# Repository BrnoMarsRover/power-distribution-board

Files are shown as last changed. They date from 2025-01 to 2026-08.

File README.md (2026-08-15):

# Power distribution board

Everything for the BrnoMarsRover power distribution board: the schematic and PCB, the
firmware that runs on it, and the ROS 2 driver that consumes it.

```
kicad/      schematic and PCB
pdf/        exported schematics
firmware/   Raspberry Pi Pico 2 sketch (Arduino, arduino-pico core)
ros2/       ROS 2 driver package (ament_python, Humble)
```

The firmware and the driver live together **because they share a versioned wire
protocol**. Every field name and status bit below is written twice - once in
`firmware/PowerBoard/Functions.cpp` and once in `ros2/powerboard/powerboard/powerboard_node.py`.
Splitting them across repositories would let the two halves be changed, reviewed and
deployed independently, and the failure mode is not a build error - it is silently
misparsed telemetry. Change the protocol in one commit, and bump `jsonSchemaVersion`
(firmware `Config.cpp`) together with `SUPPORTED_SCHEMA` (node) when you do.

## Hardware

Five INA238 current/voltage monitors on I2C, one per branch, each with a high-side
switch:

| Designator | I2C  | Shunt  | Rail | Limit |
|---|---|---|---|---|
| U2 | 0x40 | 3 mOhm | battery feed, and the master gate for the rest | 15 A |
| U3 | 0x41 | 5 mOhm | 24 V | 2.5 A |
| U4 | 0x42 | 5 mOhm | 15 V | 4 A |
| U5 | 0x43 | 5 mOhm | 12 V | 5 A |
| U6 | 0x44 | 5 mOhm | 5 V | 12 A |

Limits come from the 60 W rating of each DC-DC converter.

**Over-current protection ships disabled** (`ocpEnabled = false`). Some high-side
drivers were tripped by inrush and are bridged, so the board cannot actually switch
those branches off. Limits are still evaluated and reported, so an overload is visible
in telemetry even though nothing acts on it. `OCP ON` enables tripping if the hardware
is ever repaired.

Two things the board cannot measure, by construction:

- **Charging current.** The charger is wired on the battery side of U2's shunt, so
  charge current never crosses it. The driver infers charging from rising open-circuit
  voltage instead.
- **Currents above ~8 A on the INA CURRENT register**, which saturates there. The
  shunt-derived value is used for protection and for the `i` field because it has the
  range; `ir` is kept alongside it only for cross-checking.

## Serial protocol (schema v1)

USB CDC-ACM, one JSON object per line, telemetry at 2 Hz. Anything not starting with
`{` is human-readable diagnostics (`STATUS`, `RAW`) and is ignored by machine readers.

`"t"` gives the line type: `tel`, `evt`, `ack`, `err`, `info`.

### `tel` - periodic telemetry

```json
{"t":"tel","v":1,"seq":123,"up":61500,"ocp":0,"mst":1,"b":[ ... ]}
```

| Key | Meaning |
|---|---|
| `v` | schema version |
| `seq` | frame counter; gaps mean frames were lost |
| `up`  | milliseconds since board boot |
| `ocp` | 1 if over-current protection is enabled |
| `mst` | 1 if the U2 master branch is on |
| `b` | one object per branch |

Each branch object:

| Key | Unit | Meaning |
|---|---|---|
| `n` | | designator, `U2`..`U6` |
| `a` | | I2C address |
| `s` | | status bits, see below |
| `lim` | mA | configured current limit |
| `vb`  | V | bus voltage |
| `vs`  | mV | shunt voltage |
| `i` | mA | current derived from the shunt - **this is the real one** |
| `ir`  | mA | INA CURRENT register, saturates at ~8 A, cross-check only |
| `tc`  | degC | INA die temperature |
| `tr`  | | cumulative trip count |

Status bits in `s`:

| Bit  | Name |
|---|---|
| 0x01 | online |
| 0x02 | enabled |
| 0x04 | tripped |
| 0x08 | manual off  |
| 0x10 | powered |
| 0x20 | over limit  |

### `evt` - pushed immediately, not on the telemetry tick

```json
{"t":"evt","up":61500,"ev":"over_limit","n":"U5","i":5200.0,"lim":5000,"ocp":0}
```

`ev` is one of `over_limit`, `over_limit_clear`, `ocp_trip`, `ocp_recover`. These are
pushed as they happen because with OCP disabled an over-limit event is the only
actionable signal the board can give.

### `ack` / `err` / `info`

```json
{"t":"ack","cmd":"JSON","msg":"json output"}
{"t":"err","cmd":"OFF U9","msg":"unknown branch"}
{"t":"info","fw":"...","v":1,"rails":5,"ocp":0}
```

### Commands (host to board, one per line)

| Command | Effect |
|---|---|
| `ON <U>` | switch a branch on |
| `OFF <U>` | switch a branch off |
| `OCP [ON|OFF]` | query or set over-current protection |
| `RAW` | dump every INA238 register, human readable |
| `STATUS` | human readable summary |
| `JSON` | machine-readable output (the default) |
| `HUMAN` | switch to the plain-text table |
| `ONCE` | emit a single telemetry frame |

## Firmware

Arduino sketch in `firmware/PowerBoard`, target Raspberry Pi Pico 2 (`rpipico2`),
arduino-pico core 5.5.1. Open `PowerBoard.ino` and flash it.

## ROS 2 driver

`ros2/powerboard`, ament_python, tested on Humble. Depends only on `rclpy`,
`std_msgs`, `sensor_msgs`, `diagnostic_msgs` and `python3-serial` - no custom
interfaces.

```bash
ros2 launch powerboard powerboard.launch.py
```

| Topic | Type |
|---|---|
| `~/battery` | `sensor_msgs/BatteryState` |
| `~/rails/voltages` | `std_msgs/Float32MultiArray` |
| `~/rails/currents` | `std_msgs/Float32MultiArray` |
| `~/rails/powers` | `std_msgs/Float32MultiArray` |
| `~/events` | `std_msgs/String` |
| `~/command` | `std_msgs/String` (subscription, forwards any board command) |
| `/diagnostics` | `diagnostic_msgs/DiagnosticArray` |

The rail arrays carry names in `layout.dim[i].label`, index-aligned with `data[i]`.

State of charge is estimated from a LiPo open-circuit-voltage curve, load-compensated
and smoothed, and published in `BatteryState.percentage`. It is a rough guide, not a
fuel gauge: between about 3.8 and 3.9 V/cell the curve is nearly flat, and below
3.7 V/cell it falls away sharply. Defaults assume Freya's **10S, 14.5 Ah** pack; see
`cell_count`, `design_capacity_ah` and `pack_resistance_ohm`.

**Only one process may hold the serial port.** Two readers steal bytes from each other,
which looks exactly like a flaky board - sequence gaps and a halved frame rate.

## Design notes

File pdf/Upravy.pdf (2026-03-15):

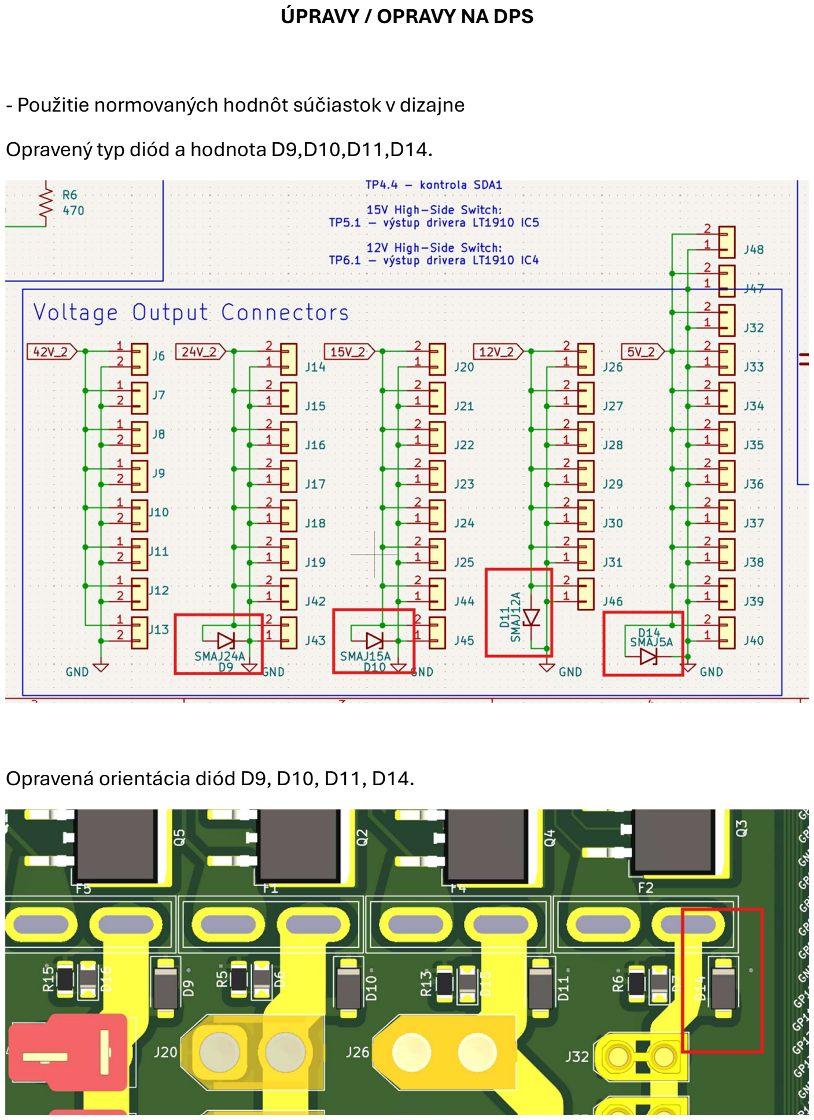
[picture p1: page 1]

ÚPRAVY / OPRAVY NA DPS

- Použitie normovaných hodnôt súčiastok v dizajne Opravený typ diód a hodnota D9,D10,D11,D14.

Opravená orientácia diód D9, D10, D11, D14.

- Zmeny hodnôt komponentov Opravene hodnoty komponentov: 5,5nF -> 5,6nF
5kOhm -> 4,7kOhm
BC818 -> BC817
- Dióda D2 a konektor J5
Boli vymazané D2 a J5, ktoré predstavovali pozostatok návrhu, ktorý uvažoval o sekundárnom zdroji energie zo solárneho panelu.
- zväčšené plôšky na Qx, L

-upravené cesty a prepoje medzi F.Cu a B.Cu

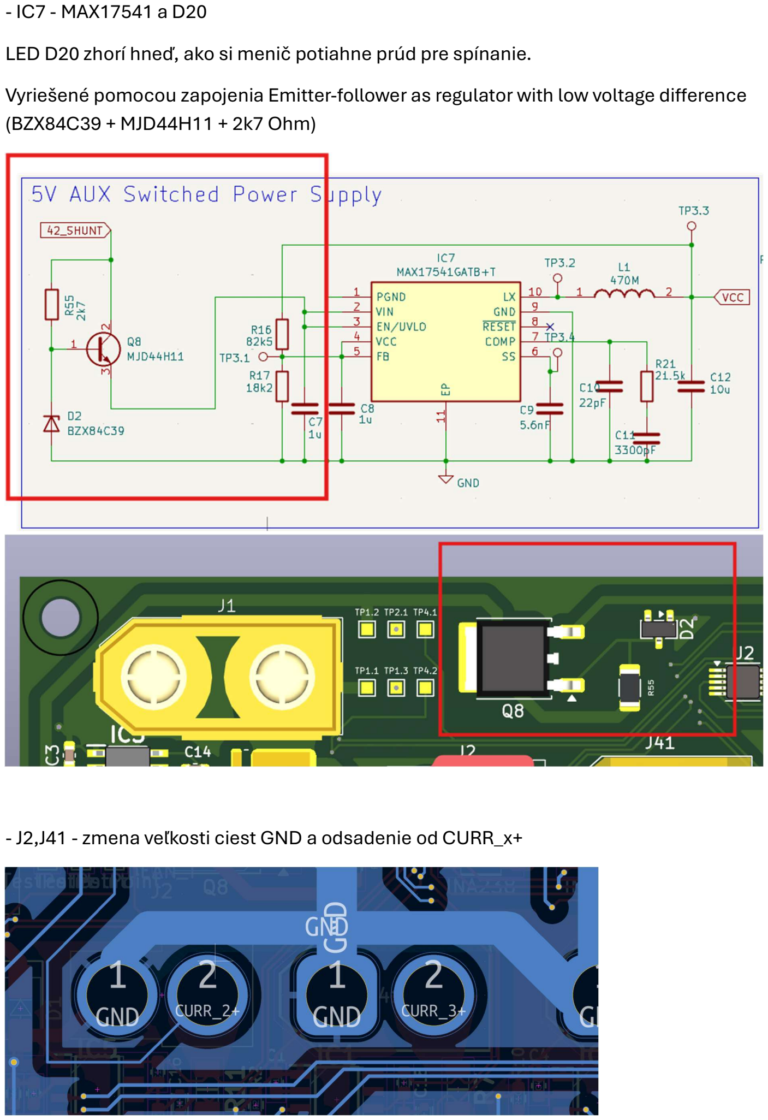
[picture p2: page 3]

- IC7 - MAX17541 a D20
LED D20 zhorí hneď, ako si menič potiahne prúd pre spínanie.
Vyriešené pomocou zapojenia Emitter-follower as regulator with low voltage dierence (BZX84C39 + MJD44H11 + 2k7 Ohm)
- J2,J41 - zmena veľkosti ciest GND a odsadenie od CURR_x+

- Chýbajúce prepojenia na DPS
Boli doplnené chýbajúce prepojenia pre: IC1 -> C1

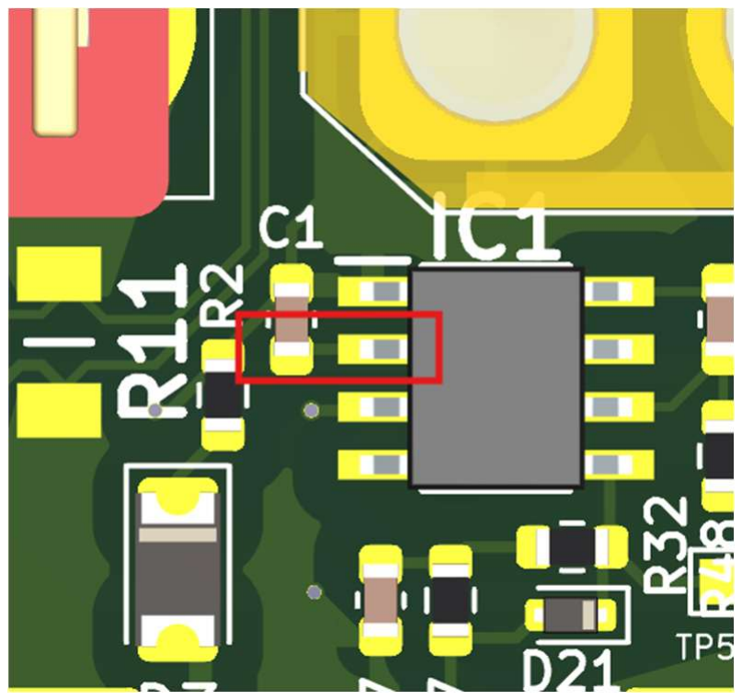
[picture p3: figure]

IC4 -> C4

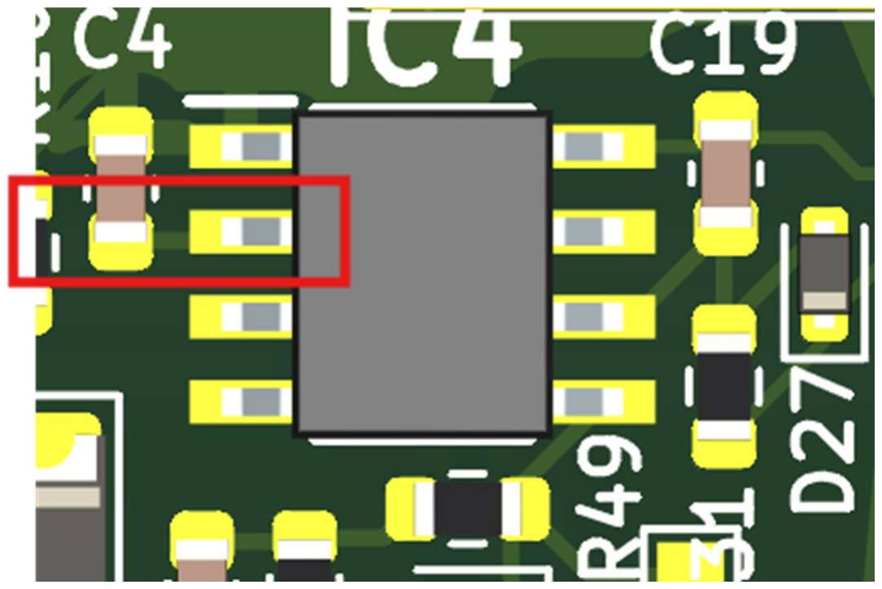
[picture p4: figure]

Q5 -> D13

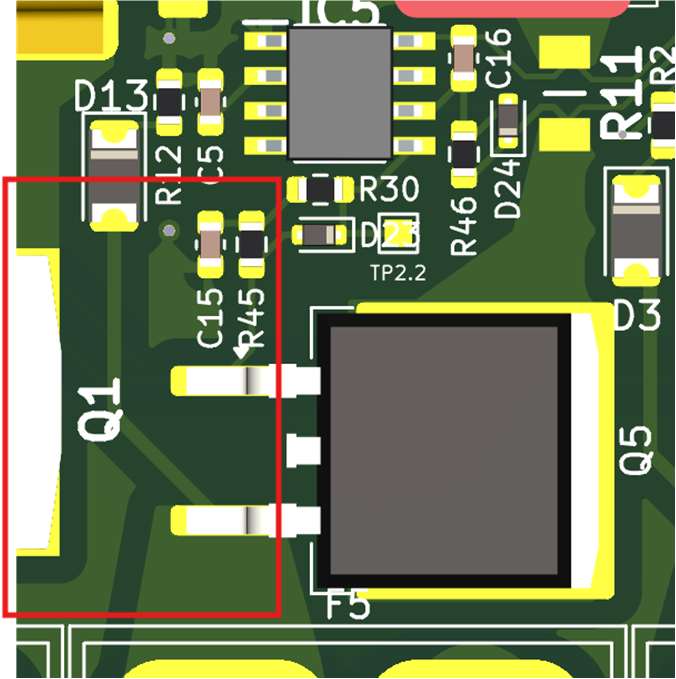
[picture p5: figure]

- test points
Boli doplnené TestPoints pre:

Battery Voltage High-Side Switch:

TP1.1 - kontrola vstupného napätia batérie

TP1.2 - napätie pred MOSFETom, kontrola shuntu

TP1.3 - kontrola gate drive IC3-Q1

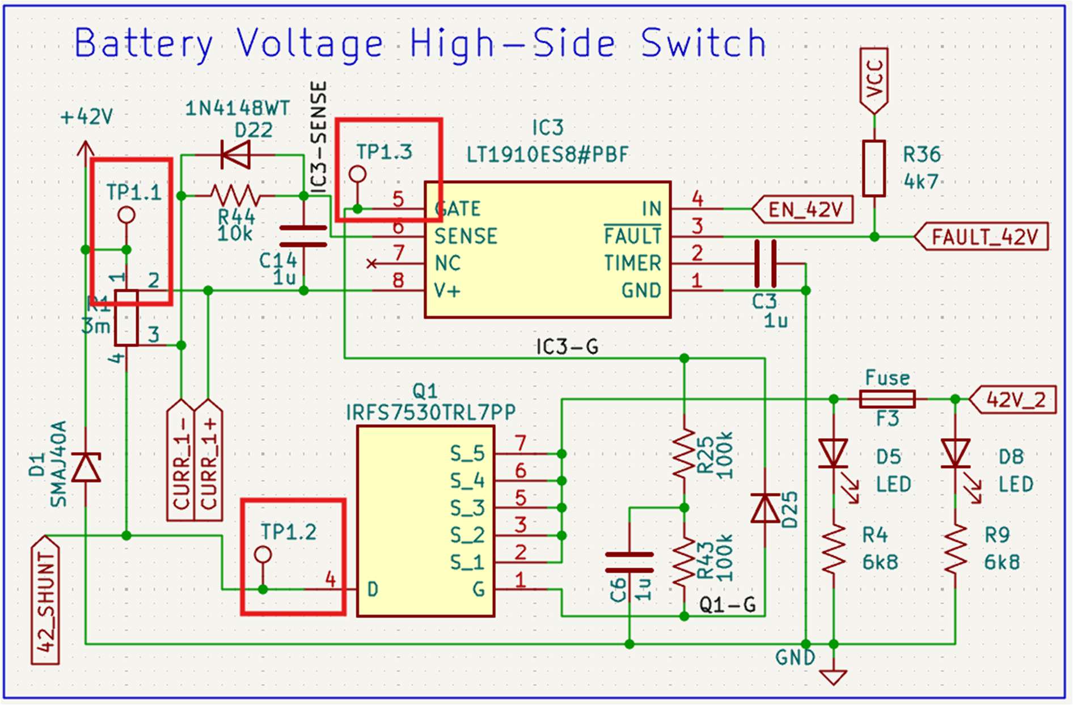
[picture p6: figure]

24V High-Side Switch:

TP2.1 - kontrola vstupného napätia 24V

TP2.2 - výstup drivera LT1910 IC5

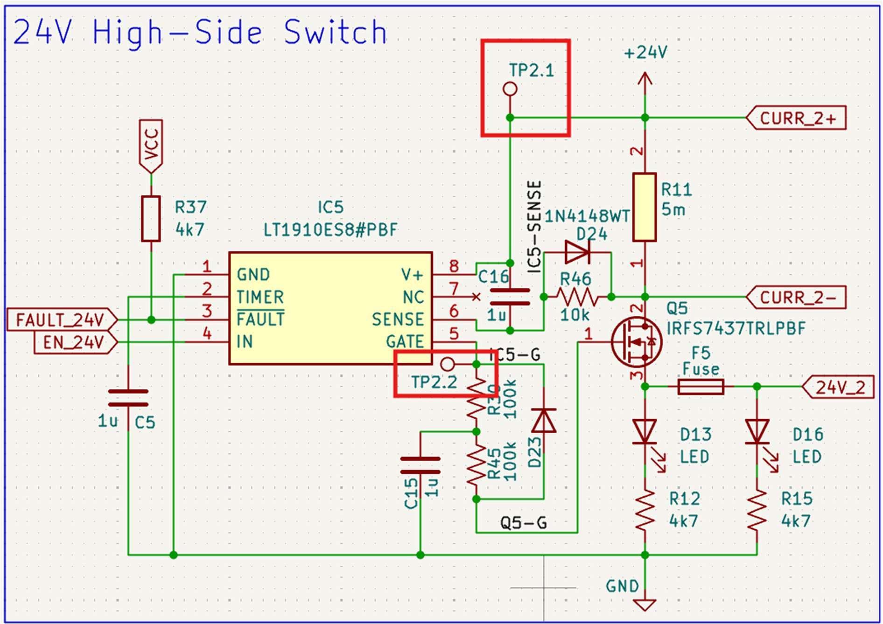
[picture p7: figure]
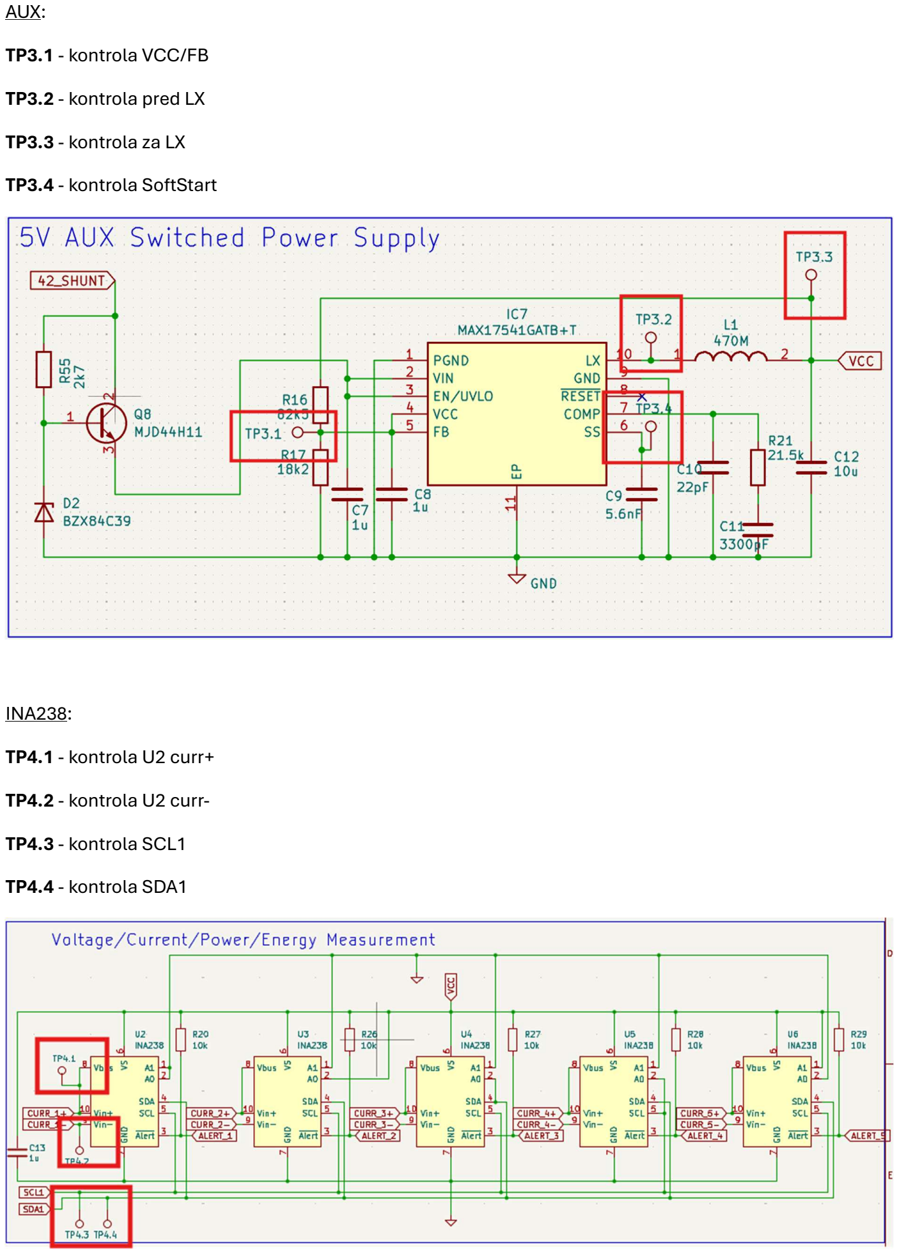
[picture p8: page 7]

AUX:

TP3.1 - kontrola VCC/FB

TP3.2 - kontrola pred LX

TP3.3 - kontrola za LX

TP3.4 - kontrola SoftStart

INA238:

TP4.1 - kontrola U2 curr+

TP4.2 - kontrola U2 curr-

TP4.3 - kontrola SCL1

TP4.4 - kontrola SDA1

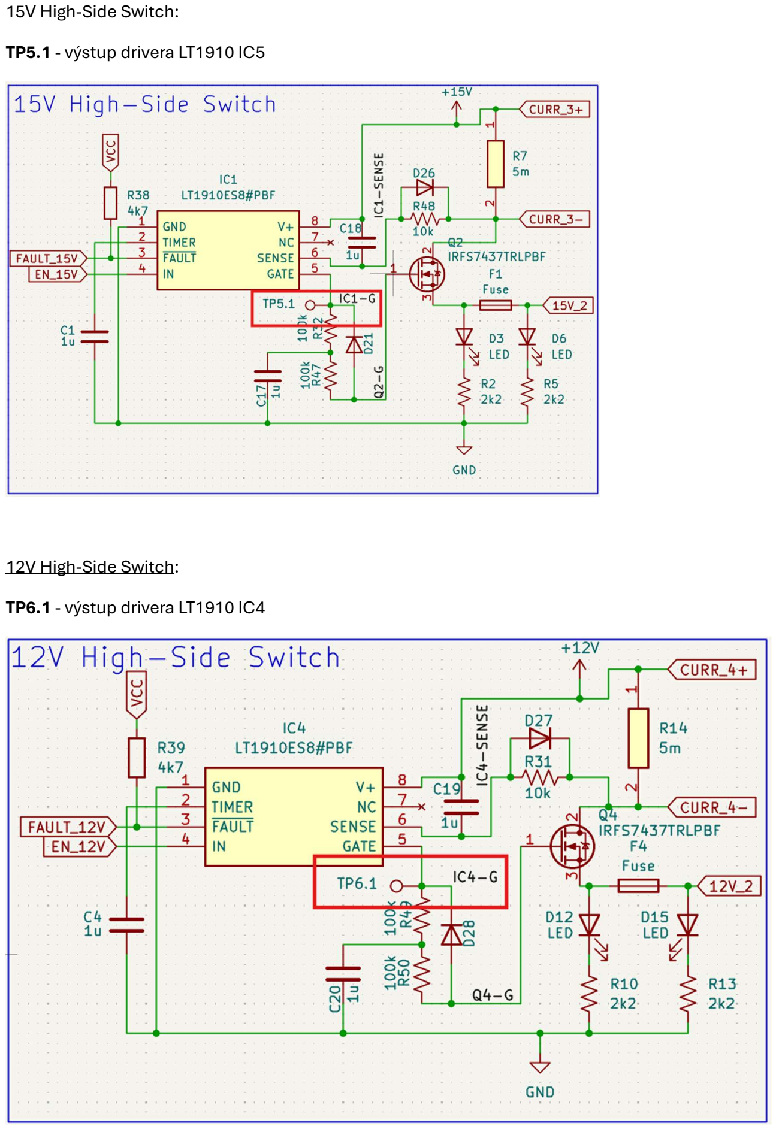
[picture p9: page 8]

15V High-Side Switch:

TP5.1 - výstup drivera LT1910 IC5

12V High-Side Switch:

TP6.1 - výstup drivera LT1910 IC4

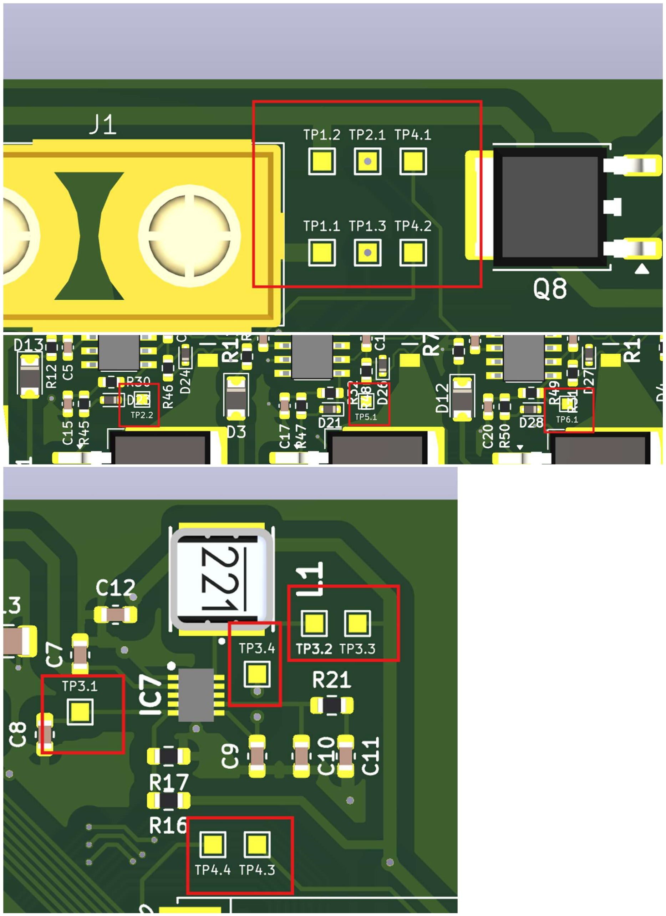
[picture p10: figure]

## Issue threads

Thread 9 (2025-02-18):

Zaintegrovat powerboard v2.3.0 spolu se zdroji a otestovat všechny napěťové úrovně

rem821, 2025-02-18:

rem821, 2025-02-21:
Při zapojení všech spínaných zdrojů se z důdovů vysoké kapacitní zátěže a tudíž vysokého startovního proudu zapne nadproudová ochrana u driveru mosfetu. Bude třeba tento vstupní proud v první chvíli omezit. Zároveň při vypínání kapacitní zátěže je nutné zamezit Ugsmax zenerkou.

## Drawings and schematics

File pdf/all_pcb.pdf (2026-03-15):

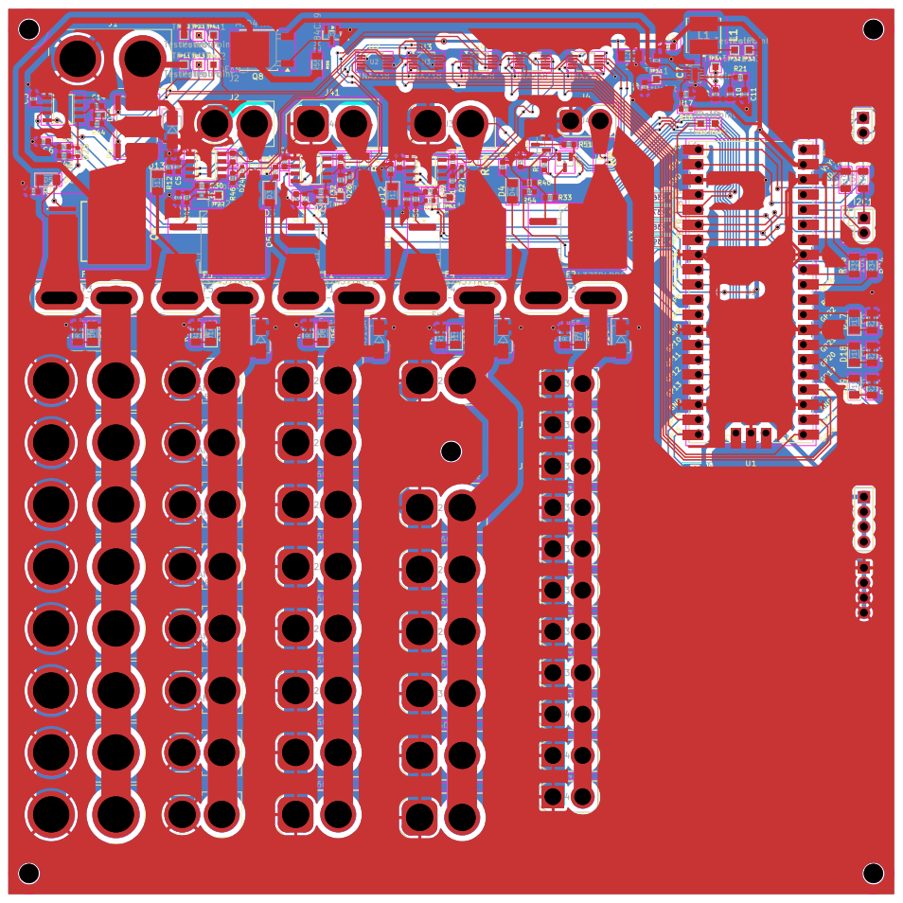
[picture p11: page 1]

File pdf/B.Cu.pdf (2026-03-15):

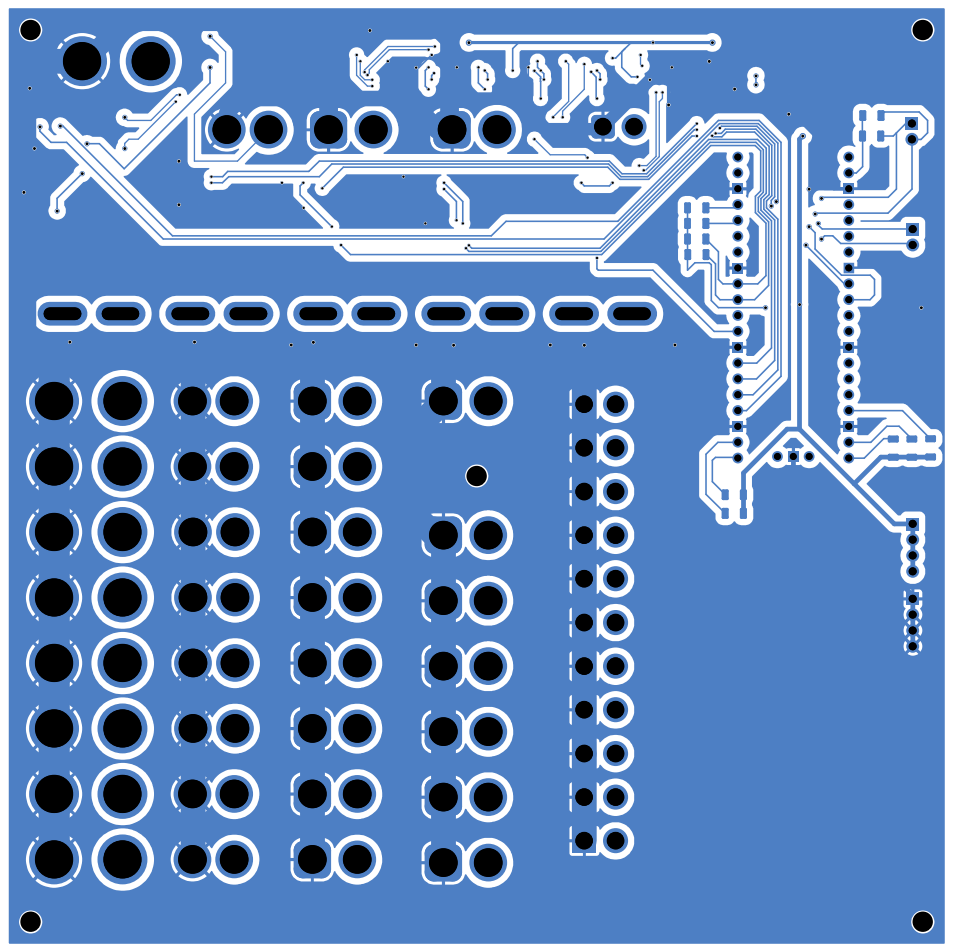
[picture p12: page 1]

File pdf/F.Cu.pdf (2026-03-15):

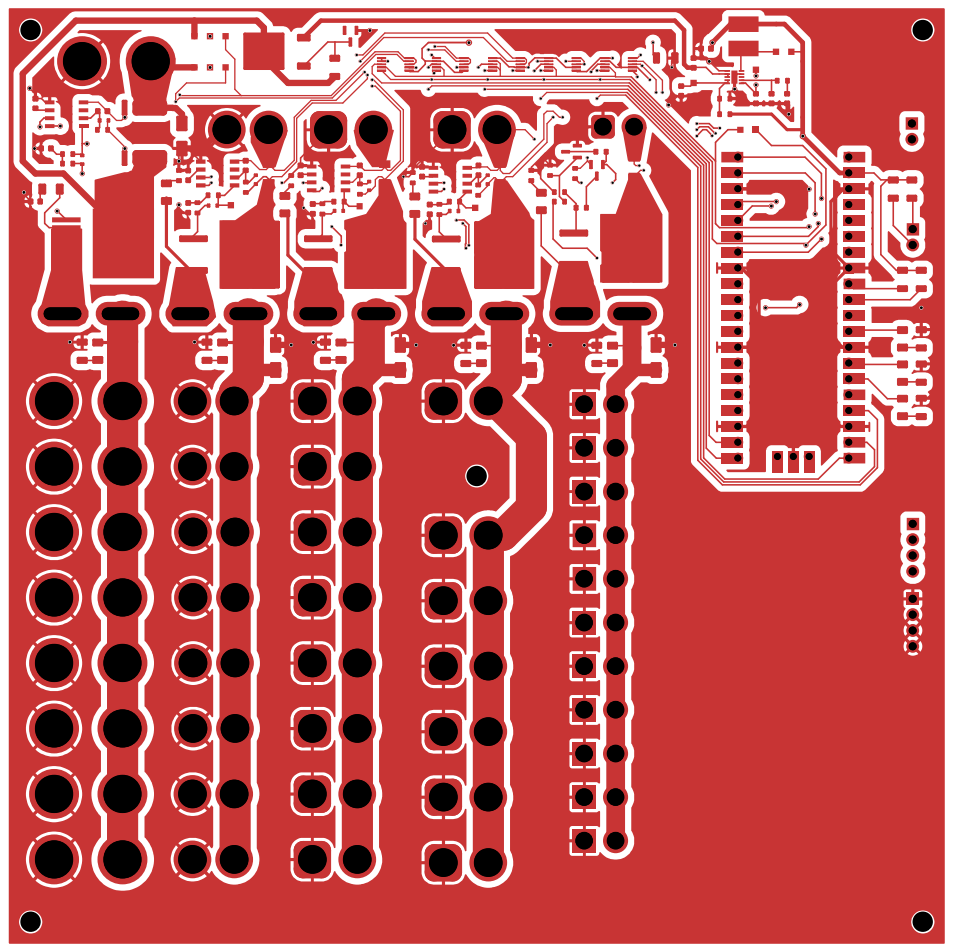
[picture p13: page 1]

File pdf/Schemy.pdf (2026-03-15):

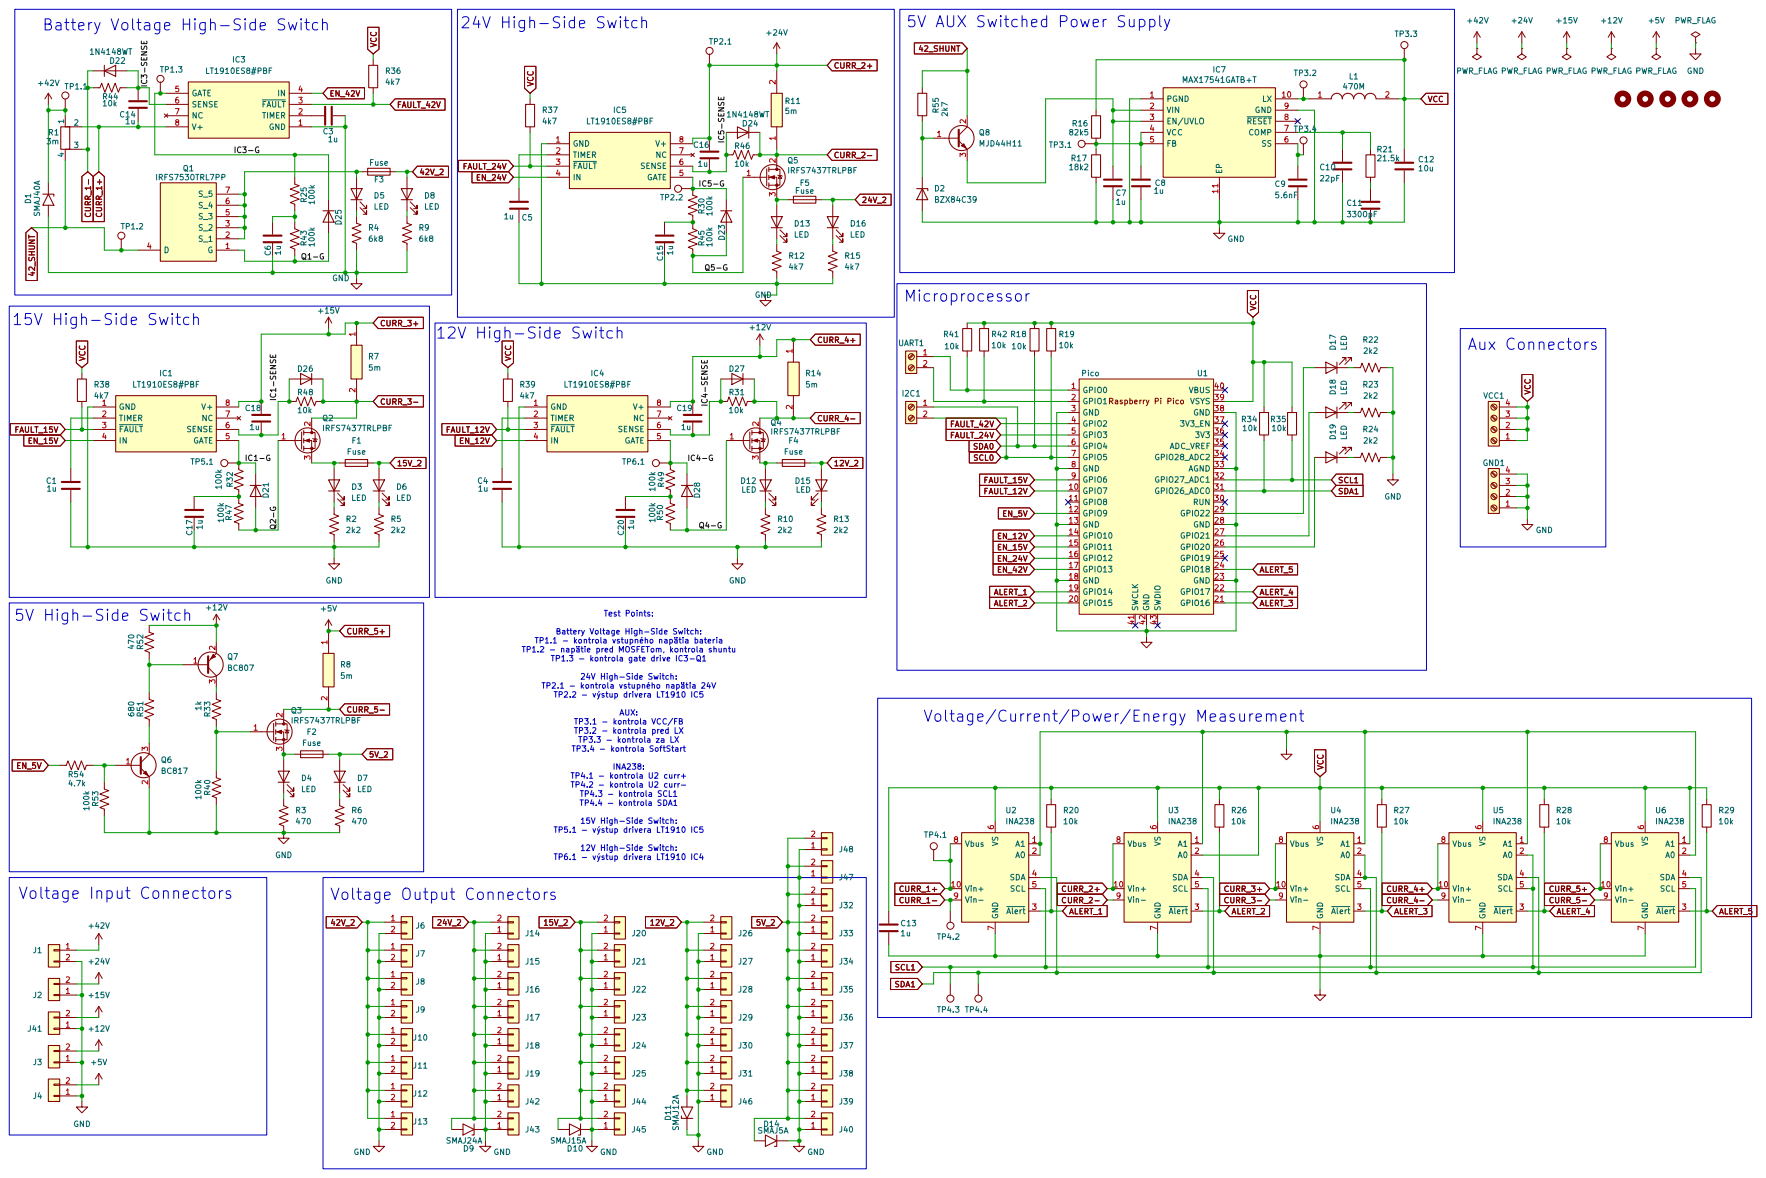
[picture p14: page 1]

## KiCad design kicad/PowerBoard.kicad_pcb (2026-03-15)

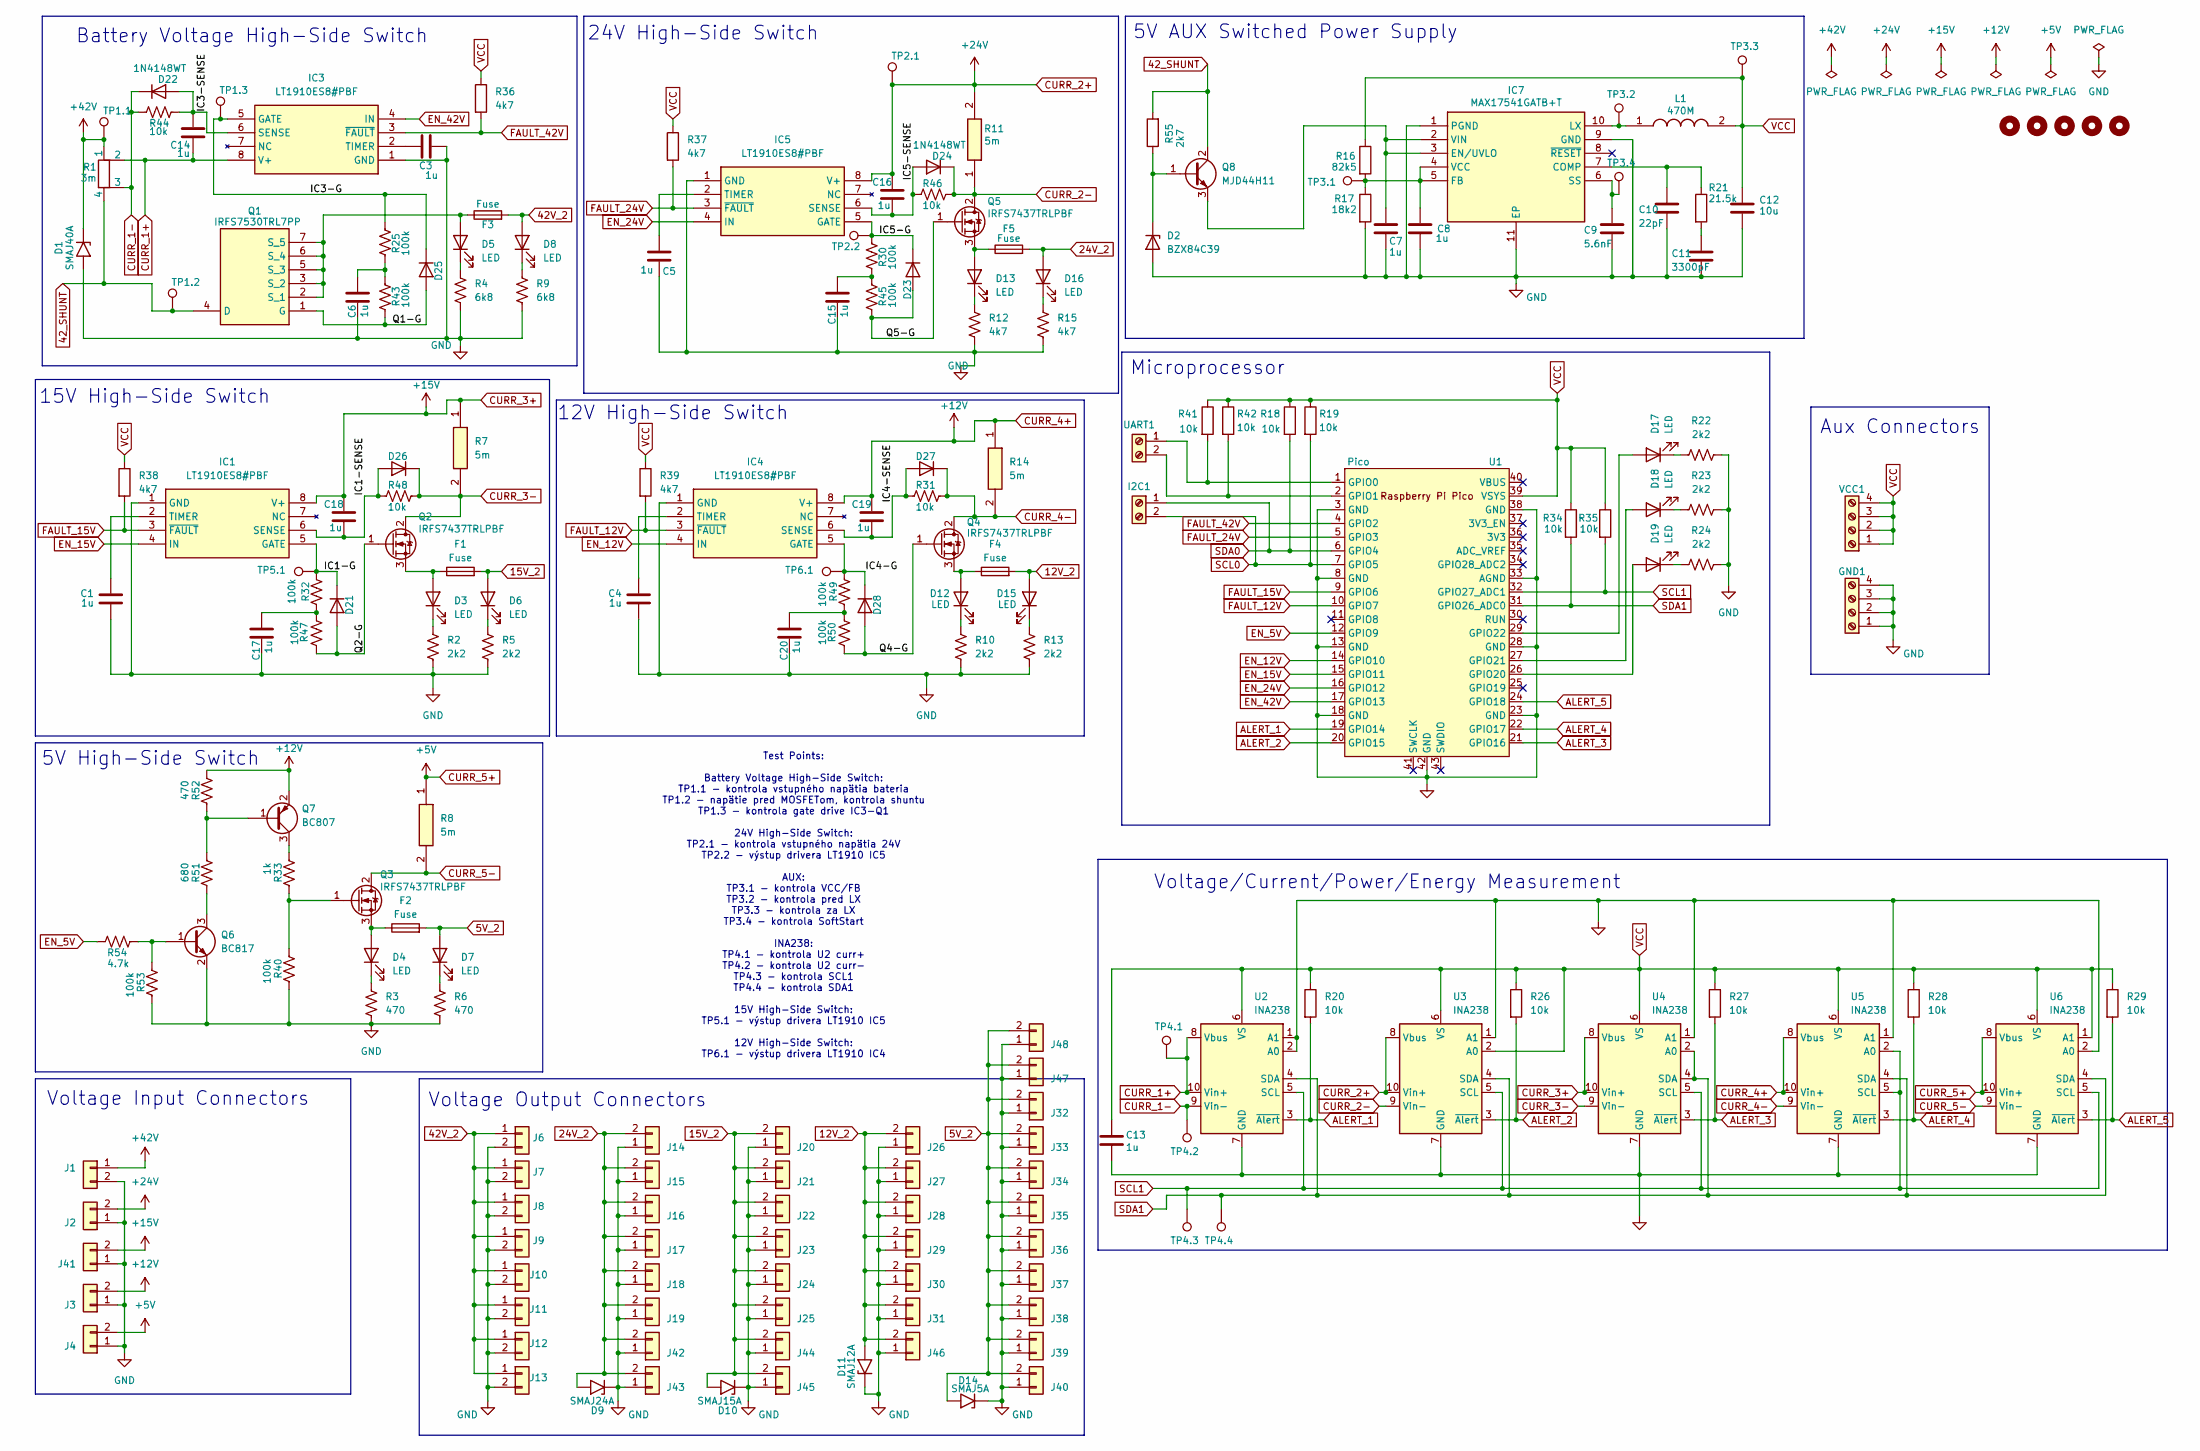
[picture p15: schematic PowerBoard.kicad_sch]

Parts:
C1, C3, C4, C5, C6, C7, C8, C14, C15, C16, C17, C18, C19, C20: 1u; C_0603_1608Metric
C9: 5.6nF; C_0603_1608Metric
C10: 22pF; C_0603_1608Metric
C11: 3300pF; C_0603_1608Metric
C12: 10u; C_0603_1608Metric
C13: 1u; C_1206_3216Metric
D1: SMAJ40A; D_SMA
D2: BZX84C39; SOT-23
D3, D4, D5, D6, D7, D8, D12, D13, D15, D16, D17, D18, D19: LED; D_1206_3216Metric
D9: SMAJ24A; D_SMA
D10: SMAJ15A; D_SMA
D11: SMAJ12A; D_SMA
D14: SMAJ5A; D_SMA
D21, D22, D23, D24, D25, D26, D27, D28: 1N4148WT; D_SOD-523
F1, F2, F3, F4, F5: Fuse; Fuse_Blade_ATO_directSolder
GND1: Screw_Terminal_01x04; TerminalBlock_Xinya_XY308-2.54-4P_1x04_P2.54mm_Horizontal
H1, H2, H3, H4, H5: MountingHole; MountingHole_3.2mm_M3
I2C1: Screw_Terminal_01x02; TerminalBlock_Xinya_XY308-2.54-2P_1x02_P2.54mm_Horizontal
IC1, IC3, IC4, IC5: LT1910ES8#PBF; SOIC127P599X175-8N; Mouser Part Number 584-LT1910ES8#PBF
IC7: MAX17541GATB+T; SON50P200X300X80-11N; Mouser Part Number 700-MAX17541GATB+T
J1, J6, J7, J8, J9, J10, J11, J12, J13: XT90
J2, J14, J15, J16, J17, J18, J19, J42, J43: DEAN_T; DEANS-T
J3, J20, J21, J22, J23, J24, J25, J26, J27, J28, J29, J30, J31, J41, J44, J45, J46: XT60; AMASS_XT60-F_1x02_P7.20mm_Vertical
J4, J32, J33, J34, J35, J36, J37, J38, J39, J40, J47, J48: XT30; AMASS_XT30U-F_1x02_P5.0mm_Vertical
L1: 470M; SRR5828A2R6Y; Mouser Part Number 6521-SRR5828A-470M
Q1: IRFS7530TRL7PP; Mouser Part Number 942-IRFS7530TRL7PP
Q2, Q3, Q4, Q5: IRFS7437TRLPBF; TO-263-2
Q6: BC817; SOT-23
Q7: BC807; SOT-23
Q8: MJD44H11; TO-252-2
R1: 3m; R_Shunt_Isabellenhuette_BVR4026
R2, R10: 2k2; R_0603_1608Metric
R3, R52: 470; R_0603_1608Metric
R4: 6k8; C_0603_1608Metric
R5, R13, R22, R23, R24: 2k2; R_1206_3216Metric
R6: 470; R_1206_3216Metric
R7, R8, R11, R14: 5m; RESC3216X89N; Mouser Part Number 71-WSL12061L000FEA
R9: 6k8; R_1206_3216Metric
R12: 4k7; R_0603_1608Metric
R15, R36, R37, R38, R39: 4k7; R_1206_3216Metric
R16: 82k5; R_0603_1608Metric
R17: 18k2; R_0603_1608Metric
R18, R19, R20, R26, R27, R28, R29, R34, R35, R41, R42: 10k; R_1206_3216Metric
R21: 21.5k; R_0603_1608Metric
R25, R30, R32, R40, R43, R45, R47, R49, R50, R53: 100k; R_0603_1608Metric
R31, R44, R46, R48: 10k; R_0603_1608Metric
R33: 1k; R_0603_1608Metric
R51: 680; R_0603_1608Metric
R54: 4.7k; R_0603_1608Metric
R55: 2k7; R_1206_3216Metric
TP1.1, TP1.2, TP1.3, TP2.1, TP2.2, TP3.1, TP3.2, TP3.3, TP3.4, TP4.1, TP4.2, TP4.3, TP4.4, TP5.1, TP6.1: TestPoint; TestPoint_Pad_1.0x1.0mm
U1: Pico; RPi_Pico_SMD_TH
U2, U3, U4, U5, U6: INA238; VSSOP-10_3x3mm_P0.5mm
UART1: Screw_Terminal_01x02; TerminalBlock_Xinya_XY308-2.54-2P_1x02_P2.54mm_Horizontal
VCC1: Screw_Terminal_01x04; TerminalBlock_Xinya_XY308-2.54-4P_1x04_P2.54mm_Horizontal

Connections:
5V_2: D7.2 (A), D14.2 (A2), F2.2, J32.2, J33.2, J34.2, J35.2, J36.2, J37.2, J38.2, J39.2, J40.2, J47.2, J48.2
12V_2: D11.2 (A2), D15.2 (A), F4.2, J26.2, J27.2, J28.2, J29.2, J30.2, J31.2, J46.2
15V_2: D6.2 (A), D10.2 (A2), F1.2, J20.2, J21.2, J22.2, J23.2, J24.2, J25.2, J44.2, J45.2
24V_2: D9.2 (A2), D16.2 (A), F5.2, J14.2, J15.2, J16.2, J17.2, J18.2, J19.2, J42.2, J43.2
42V_2: D8.2 (A), F3.2, J6.1, J7.1, J8.1, J9.1, J10.1, J11.1, J12.1, J13.1
42_SHUNT: Q1.4 (D), Q8.2 (C), R1.4, R55.2, TP1.2.1
+42V: D1.1 (A1), J1.1, R1.1, TP1.1.1
/IC1-G: D21.1 (K), IC1.5 (GATE), R32.2, TP5.1.1
/IC1-SENSE: C18.2, D26.2 (A), IC1.6 (SENSE), R48.1
/IC3-G: D25.1 (K), IC3.5 (GATE), R25.2, TP1.3.1
/IC3-SENSE: C14.1, D22.2 (A), IC3.6 (SENSE), R44.2
/IC4-G: D28.1 (K), IC4.5 (GATE), R49.2, TP6.1.1
/IC4-SENSE: C19.2, D27.2 (A), IC4.6 (SENSE), R31.1
/IC5-G: D23.1 (K), IC5.5 (GATE), R30.2, TP2.2.1
/IC5-SENSE: C16.2, D24.2 (A), IC5.6 (SENSE), R46.1
/Q1-G: D25.2 (A), Q1.1 (G), R43.2
/Q2-G: D21.2 (A), Q2.1 (G), R47.2
/Q4-G: D28.2 (A), Q4.1 (G), R50.2
/Q5-G: D23.2 (A), Q5.1 (G), R45.2
ALERT_1: R20.2, U1.19 (GPIO14), U2.3 (~Alert)
ALERT_2: R26.2, U1.20 (GPIO15), U3.3 (~Alert)
ALERT_3: R27.2, U1.21 (GPIO16), U4.3 (~Alert)
ALERT_4: R28.2, U1.22 (GPIO17), U5.3 (~Alert)
ALERT_5: R29.2, U1.24 (GPIO18), U6.3 (~Alert)
CURR_1+: C14.2, IC3.8 (V+), R1.2, TP4.1.1, U2.8 (Vbus), U2.10 (Vin+)
CURR_1-: D22.1 (K), R1.3, R44.1, TP4.2.1, U2.9 (Vin-)
CURR_2+: C16.1, IC5.8 (V+), J2.2, R11.2, TP2.1.1, U3.8 (Vbus), U3.10 (Vin+)
CURR_2-: D24.1 (K), Q5.2 (D), R11.1, R46.2, U3.9 (Vin-)
CURR_3+: C18.1, IC1.8 (V+), J41.2, R7.1, U4.8 (Vbus), U4.10 (Vin+)
CURR_3-: D26.1 (K), Q2.2 (D), R7.2, R48.2, U4.9 (Vin-)
CURR_4+: C19.1, IC4.8 (V+), J3.2, Q7.2 (E), R14.1, R52.2, U5.8 (Vbus), U5.10 (Vin+)
CURR_4-: D27.1 (K), Q4.2 (D), R14.2, R31.2, U5.9 (Vin-)
CURR_5+: J4.2, R8.1, U6.8 (Vbus), U6.10 (Vin+)
CURR_5-: Q3.2 (D), R8.2, U6.9 (Vin-)
EN_5V: R54.2, U1.12 (GPIO9)
EN_12V: IC4.4 (IN), U1.14 (GPIO10)
EN_15V: IC1.4 (IN), U1.15 (GPIO11)
EN_24V: IC5.4 (IN), U1.16 (GPIO12)
EN_42V: IC3.4 (IN), U1.17 (GPIO13)
FAULT_12V: IC4.3 (~FAULT), R39.2, U1.10 (GPIO7)
FAULT_15V: IC1.3 (~FAULT), R38.2, U1.9 (GPIO6)
FAULT_24V: IC5.3 (~FAULT), R37.2, U1.5 (GPIO3)
FAULT_42V: IC3.3 (~FAULT), R36.2, U1.4 (GPIO2)
GND: C1.2, C3.2, C4.2, C5.2, C6.1, C7.2, C8.2, C9.2, C10.2, C11.2, C12.2, C13.2, C15.1, C17.1, C20.1, D1.2 (A2), D2.1 (A), D9.1 (A1), D10.1 (A1), D11.1 (A1), D14.1 (A1), GND1.1, GND1.2, GND1.3, GND1.4, IC1.1 (GND), IC3.1 (GND), IC4.1 (GND), IC5.1 (GND), IC7.1 (PGND), IC7.9 (GND), IC7.11 (EP), J1.2, J2.1, J3.1, J4.1, J6.2, J7.2, J8.2, J9.2, J10.2, J11.2, J12.2, J13.2, J14.1, J15.1, J16.1, J17.1, J18.1, J19.1, J20.1, J21.1, J22.1, J23.1, J24.1, J25.1, J26.1, J27.1, J28.1, J29.1, J30.1, J31.1, J32.1, J33.1, J34.1, J35.1, J36.1, J37.1, J38.1, J39.1, J40.1, J41.1, J42.1, J43.1, J44.1, J45.1, J46.1, J47.1, J48.1, Q6.2 (E), R2.2, R3.2, R4.2, R5.2, R6.2, R9.2, R10.2, R12.2, R13.2, R15.2, R17.2, R22.2, R23.2, R24.2, R40.1, R53.1, U1.3 (GND), U1.8 (GND), U1.13 (GND), U1.18 (GND), U1.23 (GND), U1.28 (GND), U1.33 (AGND), U1.38 (GND), U1.42 (GND), U2.1 (A1), U2.2 (A0), U2.7 (GND), U3.1 (A1), U3.7 (GND), U4.1 (A1), U4.7 (GND), U5.1 (A1), U5.7 (GND), U6.2 (A0), U6.7 (GND)
unnamed: C6.2, R25.1, R43.1
unnamed: C11.1, R21.2
unnamed: C15.2, R30.1, R45.1
unnamed: C17.2, R32.1, R47.1
unnamed: C20.2, R49.1, R50.1
unnamed: D2.3 (K), Q8.1 (B), R55.1
unnamed: D3.2 (A), F1.1, Q2.3 (S)
unnamed: D3.1 (K), R2.1
unnamed: D4.2 (A), F2.1, Q3.3 (S)
unnamed: D4.1 (K), R3.1
unnamed: D5.2 (A), F3.1, Q1.2 (S_1), Q1.3 (S_2), Q1.5 (S_3), Q1.6 (S_4), Q1.7 (S_5)
unnamed: D5.1 (K), R4.1
unnamed: D6.1 (K), R5.1
unnamed: D7.1 (K), R6.1
unnamed: D8.1 (K), R9.1
unnamed: D12.2 (A), F4.1, Q4.3 (S)
unnamed: D12.1 (K), R10.1
unnamed: D13.2 (A), F5.1, Q5.3 (S)
unnamed: D13.1 (K), R12.1
unnamed: D15.1 (K), R13.1
unnamed: D16.1 (K), R15.1
unnamed: D17.2 (A), U1.29 (GPIO22)
unnamed: D17.1 (K), R22.1
unnamed: D18.2 (A), U1.27 (GPIO21)
unnamed: D18.1 (K), R23.1
unnamed: D19.2 (A), U1.26 (GPIO20)
unnamed: D19.1 (K), R24.1
unnamed: C1.1, IC1.2 (TIMER)
unnamed: C3.1, IC3.2 (TIMER)
unnamed: C4.1, IC4.2 (TIMER)
unnamed: C5.1, IC5.2 (TIMER)
unnamed: C10.1, IC7.7 (COMP), R21.1
unnamed: C7.1, IC7.2 (VIN), IC7.3 (EN/UVLO), Q8.3 (E)
unnamed: C8.1, IC7.4 (VCC), IC7.5 (FB), R16.2, R17.1, TP3.1.1
unnamed: IC7.10 (LX), L1.1, TP3.2.1
unnamed: C9.1, IC7.6 (SS), TP3.4.1
unnamed: Q3.1 (G), R33.1, R40.2
unnamed: Q6.1 (B), R53.2, R54.1
unnamed: Q6.3 (C), R51.1
unnamed: Q7.1 (B), R51.2, R52.1
unnamed: Q7.3 (C), R33.2
unnamed: R41.2, U1.1 (GPIO0), UART1.1
unnamed: R42.2, U1.2 (GPIO1), UART1.2
SCL0: I2C1.2, R19.2, U1.7 (GPIO5)
SCL1: R35.2, TP4.3.1, U1.32 (GPIO27_ADC1), U2.5 (SCL), U3.5 (SCL), U4.5 (SCL), U5.2 (A0), U5.5 (SCL), U6.5 (SCL)
SDA0: I2C1.1, R18.2, U1.6 (GPIO4)
SDA1: R34.2, TP4.4.1, U1.31 (GPIO26_ADC0), U2.4 (SDA), U3.4 (SDA), U4.2 (A0), U4.4 (SDA), U5.4 (SDA), U6.4 (SDA)
VCC: C12.1, C13.1, L1.2, R16.1, R18.1, R19.1, R20.1, R26.1, R27.1, R28.1, R29.1, R34.1, R35.1, R36.1, R37.1, R38.1, R39.1, R41.1, R42.1, TP3.3.1, U1.39 (VSYS), U2.6 (VS), U3.2 (A0), U3.6 (VS), U4.6 (VS), U5.6 (VS), U6.1 (A1), U6.6 (VS), VCC1.1, VCC1.2, VCC1.3, VCC1.4

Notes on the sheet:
12V High-Side Switch
24V High-Side Switch
Voltage/Current/Power/Energy Measurement
Aux Connectors
15V High-Side Switch
Microprocessor
Battery Voltage High-Side Switch
5V High-Side Switch
Test Points: Battery Voltage High-Side Switch: TP1.1 - kontrola vstupného napätia bateria TP1.2 - napätie pred MOSFETom, kontrola shuntu TP1.3 - kontrola gate drive IC3-Q1 24V High-Side Switch: TP2.1 - kontrola vstupného napätia 24V TP2.2 - výstup drivera LT1910 IC5 AUX: TP3.1 - kontrola VCC/FB TP3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
Voltage Output Connectors
Voltage Input Connectors
5V AUX Switched Power Supply

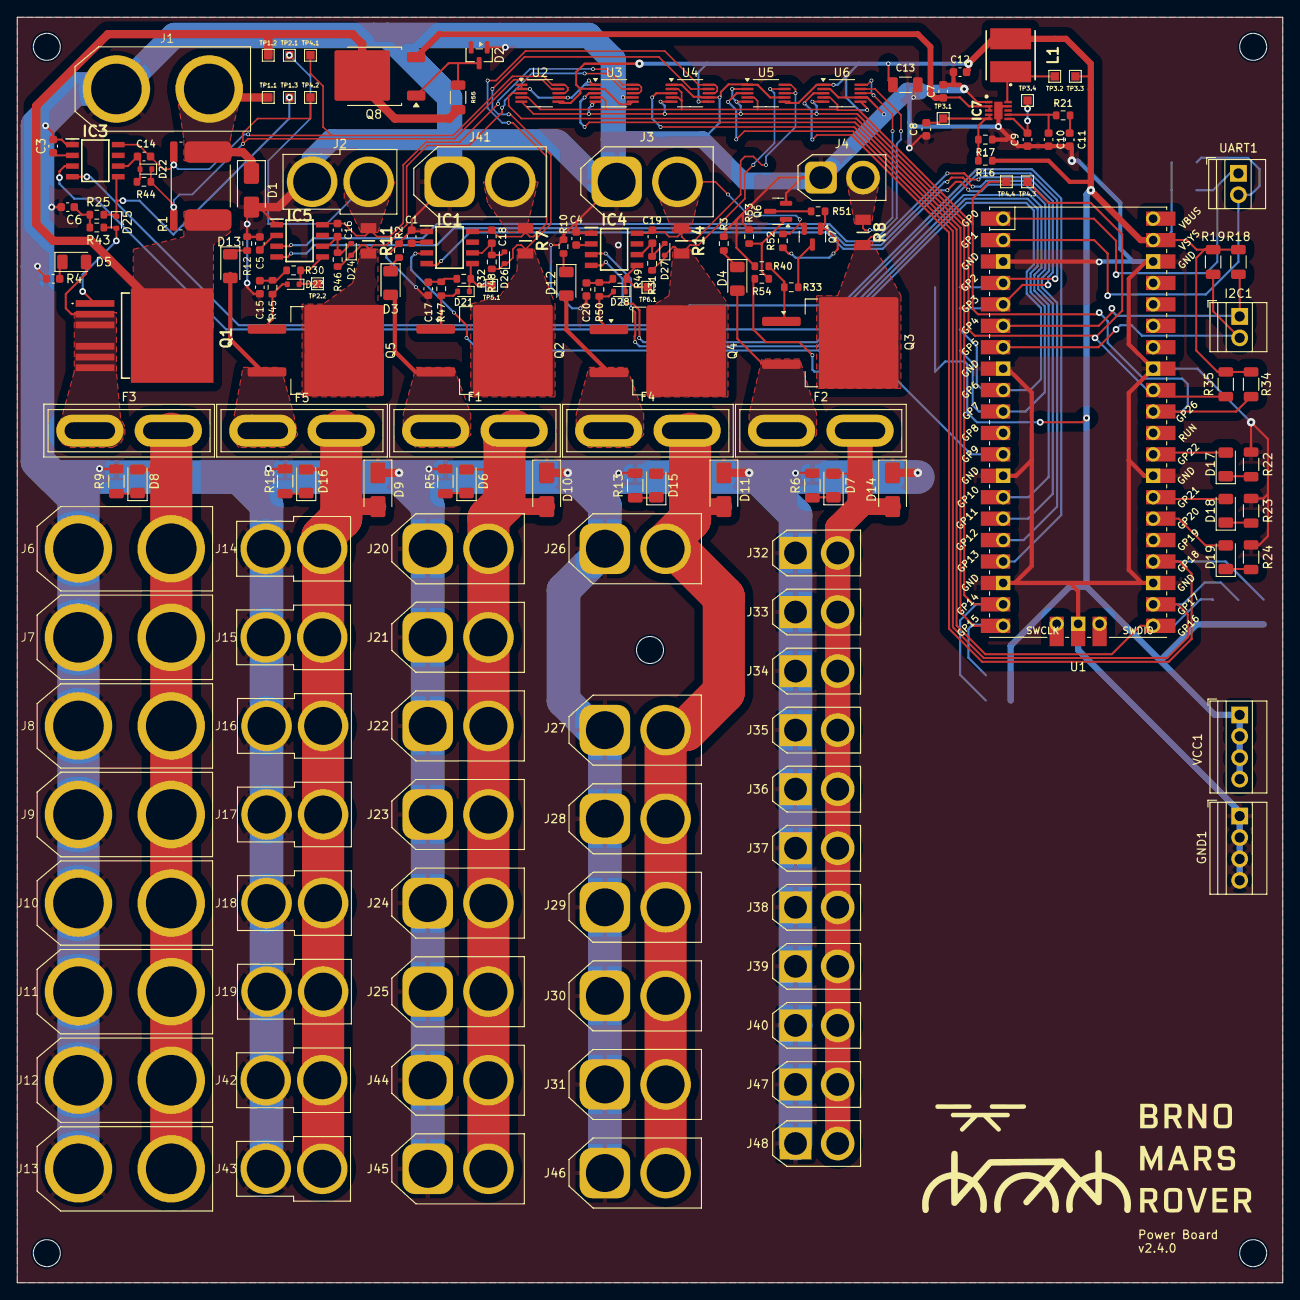
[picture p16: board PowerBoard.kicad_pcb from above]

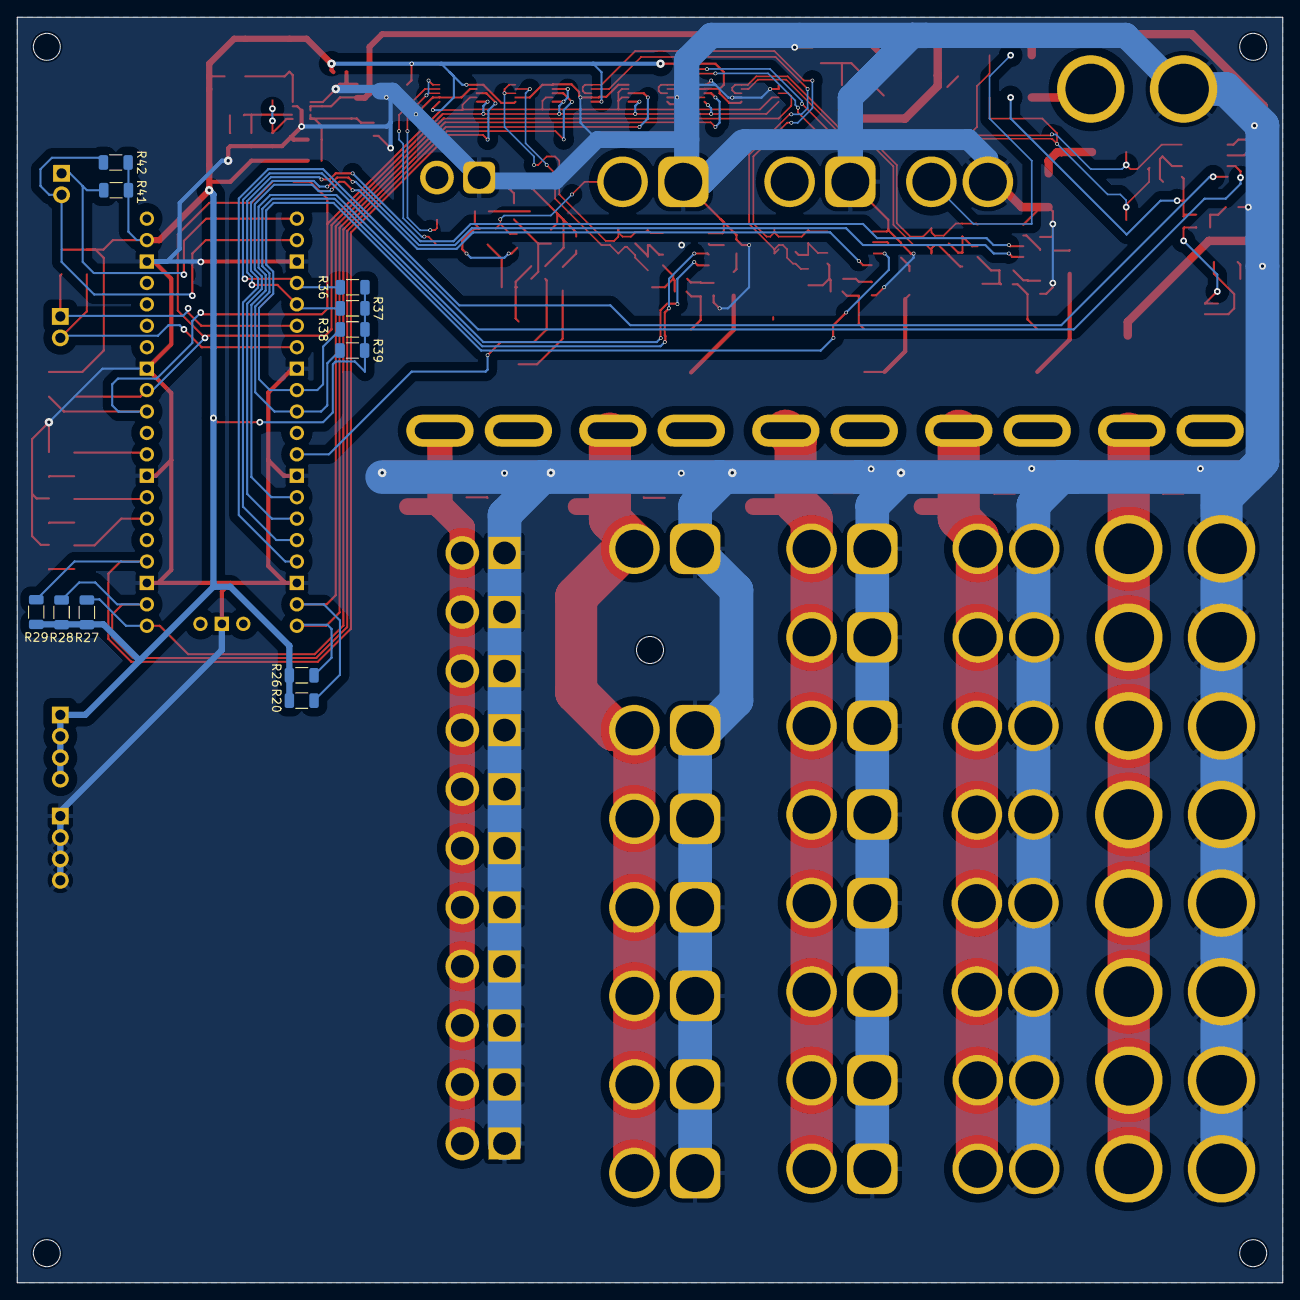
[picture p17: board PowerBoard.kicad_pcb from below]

Board: 2 copper layers, 150.0 x 150.0 mm, 197 parts (11 on the bottom side), 92 nets.

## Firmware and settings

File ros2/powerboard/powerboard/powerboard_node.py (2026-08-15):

# ROS 2 driver for the BrnoMarsRover power distribution board.
#
# The board is a Raspberry Pi Pico 2 on USB CDC-ACM emitting one JSON object per line
# at 2 Hz (firmware: BrnoMarsRover/power-distribution-board, schema v1). This node
# parses that stream and republishes it, and forwards commands back to the board.
#
# Line types on the wire, distinguished by "t":
#   tel   periodic telemetry, one per cycle
#   evt   over_limit / over_limit_clear / ocp_trip / ocp_recover, pushed immediately
#   ack   command succeeded          err   command failed
#   info  emitted once at startup, carries the schema version
# Anything that is not JSON (the STATUS and RAW human diagnostics) is ignored by design.

import json
from collections import deque

import rclpy
from rclpy.node import Node
from rclpy.qos import QoSPresetProfiles

from diagnostic_msgs.msg import DiagnosticArray, DiagnosticStatus, KeyValue
from sensor_msgs.msg import BatteryState
from std_msgs.msg import Float32MultiArray, MultiArrayDimension, String

from powerboard.serial_line_reader import SerialLineReader

# Schema this node was written against. The board reports its own in "v"; a mismatch is
# worth shouting about rather than silently misreading fields.
SUPPORTED_SCHEMA = 1

# Status bitfield in "s", as defined by the firmware.
S_ONLINE = 0x01
S_ENABLED = 0x02
S_TRIPPED = 0x04
S_MANUAL_OFF = 0x08
S_POWERED = 0x10
S_OVER_LIMIT = 0x20

# The board reports schematic designators (U2..U6), which mean nothing without the
# schematic in front of you. Map them to names a person can read. Overridable with the
# `rail_names` parameter as "U2:battery,U3:rail_24v,..." so the mapping can follow what
# each rail actually feeds without touching this file.
DEFAULT_RAIL_NAMES = {
    'U2': 'battery',      # 41 V battery feed, also the master gate for the others
    'U3': 'rail_24v',
    'U4': 'rail_15v',
    'U5': 'rail_12v',
    'U6': 'rail_5v',
}

# Resting (open-circuit) volts per cell -> state of charge, for LiPo. Freya carries a
# 10S LiPo, so a full pack is 42.0 V and 3.7 V/cell nominal is 37.0 V.
#
# Voltage is the only thing available: the board is a power monitor, not a fuel gauge,
# and coulomb counting is impossible because nothing here knows how full a pack was when
# it was plugged in, and packs get swapped.
#
# Treat the output as a rough guide, not a fuel gauge. Between roughly 3.8 and 3.9 V/cell
# the LiPo curve is almost flat, so a 0.1 V measurement error swings the answer by tens
# of percent; below ~3.7 V/cell it falls off a cliff and gets much sharper. That is the
# nature of voltage-based SoC, not a defect in this table.
LIPO_OCV_SOC = [
    (3.27, 0.00), (3.61, 0.05), (3.69, 0.10), (3.71, 0.15), (3.73, 0.20),
    (3.75, 0.25), (3.77, 0.30), (3.79, 0.35), (3.80, 0.40), (3.82, 0.45),
    (3.84, 0.50), (3.85, 0.55), (3.87, 0.60), (3.91, 0.65), (3.95, 0.70),
    (3.98, 0.75), (4.02, 0.80), (4.08, 0.85), (4.11, 0.90), (4.15, 0.95),
    (4.20, 1.00),
]


class PowerboardNode(Node):

    def __init__(self):
        super().__init__('powerboard')

        # by-id is the default because /dev/ttyACM* numbering moves when other USB
        # serial devices appear - the Xsens IMU on this NUC is exactly such a device.
        self.declare_parameter('port', '/dev/serial/by-id/usb-Raspberry_Pi_Pico_2_*-if00')
        # The board emits one frame every 500 ms, so polling faster than this buys
        # nothing but CPU. Measured on the rover's Raspberry Pi 4, the tightest machine
        # this runs on: 50 Hz cost 14.2% of a core, 20 Hz 7.1%, 10 Hz 4.5%, 5 Hz 3.4%.
        # 10 Hz adds at most 100 ms of latency to a 500 ms signal - including to pushed
        # over-limit events - which is a good trade for a third of the CPU. Nothing is
        # lost at a lower rate: the kernel buffers, and each poll drains all of it.
        self.declare_parameter('poll_rate_hz', 10.0)
        self.declare_parameter('stale_timeout_s', 3.0)
        self.declare_parameter('reconnect_period_s', 2.0)
        # Fraction of a branch's limit above which we report a warning. The board only
        # flags a hard over-limit; this gives earlier notice.
        self.declare_parameter('warn_fraction', 0.9)
        self.declare_parameter('frame_id', 'powerboard')
        # "U2:battery,U3:rail_24v" - anything unlisted keeps its designator.
        self.declare_parameter('rail_names', '')

        # -- battery state of charge -----------------------------------------------
        # Freya's pack is 10S LiPo. Set to 0 to publish NaN instead of an estimate.
        self.declare_parameter('cell_count', 10)
        # Whole-pack internal resistance, used to recover open-circuit voltage from the
        # loaded terminal voltage: without it the estimate dips whenever the motors pull
        # and springs back when they stop. ~6 mOhm per cell is typical for a pack this
        # size; measure it by taking (V_idle - V_loaded) / current and set it here.
        self.declare_parameter('pack_resistance_ohm', 0.06)
        # The curve is steep near empty and the load varies fast, so smooth the result.
        # This is a display quantity - lag is much cheaper than a jumpy number.
        self.declare_parameter('soc_filter_tau_s', 30.0)
        self.declare_parameter('soc_warn_percent', 25.0)
        self.declare_parameter('soc_error_percent', 15.0)
        # Nameplate capacity of the pack, in Ah. Used for BatteryState.design_capacity,
        # for restating the estimate in Ah, and for the runtime estimate. 0 disables all
        # three. BatteryState.capacity - the capacity this pack can still hold after
        # ageing - stays NaN, because nothing here measures it and copying the nameplate
        # figure into it would assert the pack is as-new.
        self.declare_parameter('design_capacity_ah', 14.5)
        # Charging is INVISIBLE to this board: the charger sits on the battery side of
        # U2's shunt, so charge current never crosses it and the shunt only ever sees
        # the rover's own draw. It has to be inferred instead, from the one signature
        # that a discharging pack cannot produce - open-circuit voltage rising while a
        # normal load current is flowing.
        #
        # Threshold sits between the two measured rates: the real charger gives about
        # +4.2 mV per cell per minute (+2.5 V/h at the pack), while a resting pack drifts
        # by well under 1 mV per cell per minute - quantisation is 0.31 mV/cell and the
        # load compensation contributes about 0.24 mV/cell at the observed current
        # ripple. 2 mV/cell is roughly twice the noise and half the signal.
        #
        # Known blind spot: near full, the charger moves to constant voltage, the current
        # tapers and the rise flattens out, so detection drops back to "not charging".
        # That is benign - by then the estimate is near 100% anyway.
        self.declare_parameter('charge_detect_window_s', 60.0)
        self.declare_parameter('charge_detect_rise_v_per_cell', 0.002)
        self.declare_parameter('charge_detect_enabled', True)

        self.port_pattern = self.get_parameter('port').value
        self.stale_timeout = float(self.get_parameter('stale_timeout_s').value)
        self.warn_fraction = float(self.get_parameter('warn_fraction').value)
        self.frame_id = self.get_parameter('frame_id').value
        self.rail_names = self._parse_rail_names(self.get_parameter('rail_names').value)
        self.cell_count = int(self.get_parameter('cell_count').value)
        self.pack_resistance = float(self.get_parameter('pack_resistance_ohm').value)
        self.soc_tau = float(self.get_parameter('soc_filter_tau_s').value)
        self.soc_warn = float(self.get_parameter('soc_warn_percent').value)
        self.soc_error = float(self.get_parameter('soc_error_percent').value)
        self.design_capacity = float(self.get_parameter('design_capacity_ah').value)
        self.charge_window = float(self.get_parameter('charge_detect_window_s').value)
        self.charge_rise = float(self.get_parameter('charge_detect_rise_v_per_cell').value)
        self.charge_detect = bool(self.get_parameter('charge_detect_enabled').value)

        self.reader = SerialLineReader(self.port_pattern)

        # -- publishers ------------------------------------------------------------
        self.diag_pub = self.create_publisher(DiagnosticArray, '/diagnostics', 10)
        # U2 is the actual battery feed, so BatteryState is a genuine fit there. The
        # derived rails are not batteries, so they go into the RailArray topics below
        # rather than being forced into a message that promises charge state they do
        # not have.
        # State of charge rides in BatteryState.percentage (0..1, per the ROS convention
        # for that field). There was briefly a separate ~/battery/percentage Float32 in
        # percent, but it carried the same number scaled by 100 - two sources of one
        # truth, free to drift apart. /diagnostics already has soc_percent for anyone who
        # wants percent rather than a fraction.
        self.battery_pub = self.create_publisher(BatteryState, '~/battery', 10)
        self.event_pub = self.create_publisher(
            String, '~/events', QoSPresetProfiles.SENSOR_DATA.value)
        # One message per quantity rather than a topic per rail: a consumer almost
        # always wants the whole set at one instant, and separate topics cannot be
        # correlated to a single sample.
        #
        # Float32MultiArray keeps this to standard messages - no custom interface for
        # consumers to build. data[i] is index aligned with layout.dim[i].label, which
        # carries the readable rail name, so the arrays stay self describing. That is a
        # mild stretch of MultiArrayLayout, whose dims are really meant to describe
        # tensor shape, but it beats publishing bare numbers whose meaning depends on
        # remembering the order. /diagnostics carries the same values fully named if
        # you want the unambiguous view.
        self.voltages_pub = self.create_publisher(Float32MultiArray, '~/rails/voltages', 10)
        self.currents_pub = self.create_publisher(Float32MultiArray, '~/rails/currents', 10)
        self.powers_pub = self.create_publisher(Float32MultiArray, '~/rails/powers', 10)

        # -- command input ---------------------------------------------------------
        # A String topic rather than services: it exposes the board's full command set
        # (ON/OFF per branch, OCP ON/OFF, RAW, HUMAN) without inventing a custom srv
        # for each. Anything not understood comes back as an "err" line.
        self.create_subscription(String, '~/command', self._on_command, 10)

        # -- state -----------------------------------------------------------------
        self._last_frame_time = None
        self._last_seq = None
        self._seq_gaps = 0
        self._board_schema = None
        self._parse_errors = 0
        self._reported_stale = False
        self._soc = None            # filtered, 0..1
        self._soc_raw = None        # this sample only, 0..1
        self._soc_time = None
        self._v_cell = None
        self._ocv_cell = None
        self._current_A = 0.0
        self._charging = False
        self._ocv_history = deque()   # (t, volts per cell), trimmed to the window
        self._ocv_rise = 0.0          # volts per cell across the window, signed

        poll_period = 1.0 / max(1.0, float(self.get_parameter('poll_rate_hz').value))
        self.create_timer(poll_period, self._poll)
        self.create_timer(float(self.get_parameter('reconnect_period_s').value),
                          self._ensure_connected)
        self.create_timer(1.0, self._check_stale)

        self.get_logger().info(f"powerboard node started, looking for {self.port_pattern}")

    @staticmethod
    def _parse_rail_names(spec):
        names = dict(DEFAULT_RAIL_NAMES)
        for pair in (spec or '').split(','):
            pair = pair.strip()
            if not pair or ':' not in pair:
                continue
            designator, human = pair.split(':', 1)
            names[designator.strip()] = human.strip()
        return names

    def _rail_name(self, designator):
        """Readable name for a rail, falling back to the designator if unmapped."""
        return self.rail_names.get(designator, designator)

    # -- connection ----------------------------------------------------------------

    def _ensure_connected(self):
        if self.reader.connected:
            return
        path = self.reader.connect()
        if path is None:
            return
        self.get_logger().info(f"connected to {path}")
        # The board may have been left in HUMAN mode by someone with a terminal open.
        # Asking for JSON makes the node self-correcting rather than silently seeing
        # nothing it can parse.
        self.reader.write_line('JSON')

    def _drop_connection(self, reason):
        if self.reader.connected:
            self.get_logger().warn(f"disconnected: {reason}")
        self.reader.close()
        self._last_seq = None

    # -- reading -------------------------------------------------------------------

    def _poll(self):
        if not self.reader.connected:
            return
        try:
            lines = self.reader.poll()
        except OSError as exc:
            self._drop_connection(str(exc))
            return
        for line in lines:
            self._handle_line(line)

    def _handle_line(self, line):
        if not line:
            return
        # STATUS and RAW output is human text on the same stream by design, so a line
        # that is not JSON is skipped rather than treated as an error.
        if not line.startswith('{'):
            return
        try:
            msg = json.loads(line)
        except ValueError:
            self._parse_errors += 1
            return

        kind = msg.get('t')
        if kind == 'tel':
            self._handle_telemetry(msg)
        elif kind == 'evt':
            self._handle_event(msg)
        elif kind in ('ack', 'err'):
            text = f"{msg.get('cmd', '?')}: {msg.get('msg', '')}"
            if kind == 'ack':
                self.get_logger().info(f"board ack {text}")
            else:
                self.get_logger().warn(f"board err {text}")
        elif kind == 'info':
            self._board_schema = msg.get('v')
            self.get_logger().info(
                f"board fw={msg.get('fw')} schema=v{msg.get('v')} "
                f"rails={msg.get('rails')} ocp={msg.get('ocp')}")
            self._check_schema()

    def _handle_event(self, msg):
        ev = msg.get('ev', '?')
        designator = msg.get('n', '?')
        name = f"{self._rail_name(designator)} ({designator})"
        text = (f"{ev} {name} i={msg.get('i')}mA lim={msg.get('lim')}mA "
                f"ocp={msg.get('ocp')}")
        # Over-limit with OCP disabled is the case that matters most on this board:
        # nothing will be switched off, so the log is the only warning anyone gets.
        if ev in ('over_limit', 'ocp_trip'):
            self.get_logger().error(f"POWERBOARD EVENT: {text}")
        else:
            self.get_logger().info(f"powerboard event: {text}")
        out = String()
        out.data = json.dumps(msg, separators=(',', ':'))
        self.event_pub.publish(out)

    def _check_schema(self):
        if self._board_schema is not None and self._board_schema != SUPPORTED_SCHEMA:
            self.get_logger().error(
                f"board reports schema v{self._board_schema} but this node understands "
                f"v{SUPPORTED_SCHEMA}; fields may be misread")

    # -- telemetry -----------------------------------------------------------------

    def _handle_telemetry(self, msg):
        now = self.get_clock().now()
        self._last_frame_time = now
        if self._reported_stale:
            self.get_logger().info("powerboard stream recovered")
            self._reported_stale = False

        if self._board_schema is None:
            self._board_schema = msg.get('v')
            self._check_schema()

        # A gap means frames were dropped somewhere. Without this, stale or thinned
        # data is indistinguishable from healthy data.
        seq = msg.get('seq')
        if seq is not None and self._last_seq is not None:
            expected = (self._last_seq + 1) & 0xFFFFFFFF
            if seq != expected:
                self._seq_gaps += 1
                self.get_logger().warn(
                    f"telemetry gap: expected seq {expected}, got {seq}")
        self._last_seq = seq

        ocp_enabled = bool(msg.get('ocp', 0))
        master_on = bool(msg.get('mst', 1))
        branches = msg.get('b', [])

        diag = DiagnosticArray()
        diag.header.stamp = now.to_msg()
        diag.header.frame_id = self.frame_id

        labels, volts, amps, watts = [], [], [], []
        for br in branches:
            diag.status.append(self._branch_status(br, ocp_enabled, master_on))
            designator = br.get('n', '?')
            voltage = float(br.get('vb', 0.0))
            current_mA = float(br.get('i', 0.0))
            # Keep the designator in the label as well: the schematic, the firmware and
            # anyone holding a multimeter all speak in U-numbers.
            labels.append(f'{self._rail_name(designator)}({designator})')
            volts.append(voltage)
            amps.append(current_mA)
            watts.append(voltage * current_mA / 1000.0)
            if br.get('a') == 0x40:          # U2, the battery feed
                self._publish_battery(br, now)

        self.voltages_pub.publish(self._rail_array(labels, volts, 'V'))
        self.currents_pub.publish(self._rail_array(labels, amps, 'mA'))
        self.powers_pub.publish(self._rail_array(labels, watts, 'W'))

        if self._soc is not None:
            diag.status.append(self._charge_status())
        diag.status.append(self._board_status(msg, ocp_enabled, master_on))
        self.diag_pub.publish(diag)

    def _charge_status(self):
        pct = self._soc * 100.0
        st = DiagnosticStatus()
        st.name = 'powerboard: battery charge'
        st.hardware_id = self.frame_id

        if self._charging:
            # Never ERROR while charging: the pack is being dealt with, and a red alarm
            # that nobody can act on is noise. It stays a warning rather than OK because
            # the number is an over-estimate - the charger holds the terminal voltage
            # above the pack's true open-circuit voltage, and by exactly how much cannot
            # be known without seeing the charge current.
            st.level = (DiagnosticStatus.OK if pct > self.soc_warn
                        else DiagnosticStatus.WARN)
            st.message = (f'charging, {pct:.0f}% (estimate reads high while on charge; '
                          f'true value settles a few minutes after unplugging)')
        elif pct <= self.soc_error:
            st.level = DiagnosticStatus.ERROR
            st.message = f'battery critically low, {pct:.0f}% - stop and swap the pack'
        elif pct <= self.soc_warn:
            st.level = DiagnosticStatus.WARN
            st.message = f'battery low, {pct:.0f}%'
        else:
            st.level = DiagnosticStatus.OK
            st.message = f'{pct:.0f}%'

        st.values = [
            KeyValue(key='soc_percent', value=f'{pct:.1f}'),
            # Unfiltered, so a sudden drop is visible before the smoothed value catches up.
            KeyValue(key='soc_percent_unfiltered', value=f'{self._soc_raw * 100.0:.1f}'),
            KeyValue(key='volts_per_cell_loaded', value=f'{self._v_cell:.3f}'),
            KeyValue(key='volts_per_cell_open_circuit', value=f'{self._ocv_cell:.3f}'),
            KeyValue(key='cell_count', value=str(self.cell_count)),
            KeyValue(key='pack_resistance_ohm', value=f'{self.pack_resistance:.3f}'),
            KeyValue(key='estimator', value='LiPo open-circuit voltage curve, load compensated'),
            KeyValue(key='charging', value=str(self._charging)),
            # Inferred, because the charger is wired on the battery side of the shunt and
            # its current never crosses it.
            KeyValue(key='charging_detected_from',
                     value=f'OCV trend {self._ocv_rise * 1000.0:+.1f} mV/cell '
                           f'over {self.charge_window:.0f} s'),
        ]

        if self.design_capacity > 0.0:
            remaining_Ah = self._soc * self.design_capacity
            st.values.append(KeyValue(key='design_capacity_Ah',
                                      value=f'{self.design_capacity:.2f}'))
            st.values.append(KeyValue(key='remaining_Ah', value=f'{remaining_Ah:.2f}'))
            # Straight-line extrapolation of the current draw. Honest for a steady load,
            # optimistic the moment the rover starts driving, and meaningless once the
            # voltage curve goes soft near empty - so it is a hint, not a countdown.
            if self._charging:
                # Time-to-full would need the charge current, which is the one thing
                # this board cannot see. Better to say so than to print a number.
                st.values.append(KeyValue(key='estimated_runtime_min',
                                          value='n/a (charging)'))
            elif self._current_A >= 0.05:
                st.values.append(KeyValue(
                    key='estimated_runtime_min',
                    value=f'{remaining_Ah / self._current_A * 60.0:.0f}'))
            else:
                st.values.append(KeyValue(key='estimated_runtime_min',
                                          value='n/a (no significant load)'))
        return st
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

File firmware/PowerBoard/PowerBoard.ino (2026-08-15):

#include <Wire.h>
#include "INA238.h"

#include "Globals.h"
#include "Config.h"
#include "Functions.h"

void setup()
{
    Serial.begin(115200);
    while (!Serial && millis() < 10000UL);

    initializeSystem();
}

void loop()
{
    processSerialCommand();
    readINAData();
    printOutput();   // JSON by default, human table after the HUMAN command
    delay(500);
}

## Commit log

2024-10-11 added status leds
    [PowerBoard.kicad_pcb, PowerBoard.kicad_sch]
2024-11-01 changed i2c connection
    [PowerBoard-B_Cu.gbr, PowerBoard-B_Mask.gbr, PowerBoard-B_Paste.gbr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]
2024-11-01 added spi and i2c terminals
    [PowerBoard-B_Cu.gbr, PowerBoard-B_Mask.gbr, PowerBoard-B_Paste.gbr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]
2024-12-02 Remove unused switch on the battery rail
    [PowerBoard.kicad_sch]
2024-12-03 Add LTC7004 driver
    [PowerBoard.kicad_pcb, PowerBoard.kicad_sch]
2024-12-03 iterate the layoutL
    [PowerBoard.kicad_pcb, PowerBoard.kicad_sch]
2024-12-05 fix the layout
    [PowerBoard.kicad_pcb, PowerBoard.kicad_sch]
2024-12-06 change input mosfet for a supported one
2024-12-13 Finish the design
    [PowerBoard.kicad_pcb, PowerBoard.kicad_sch]
2024-12-21 add base resistors for the power mosfets
    [PowerBoard.kicad_pcb, PowerBoard.kicad_sch]
2024-12-21 change shunt value
    [PowerBoard.kicad_sch]
2024-12-21 Adjust resistor and transil values
    [PowerBoard.kicad_sch]
2024-12-21 update bom
    [bom.xls]
2024-12-28 remove solder mask from high current traces and optimize vias for cheaper manufacturing process
    [PowerBoard-B_Cu.gbr, PowerBoard-B_Mask.gbr, PowerBoard-B_Silkscreen.gbr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]
2025-01-23 safety features added, uart connector added
    [PowerBoard.kicad_pcb, PowerBoard.kicad_sch, bom.xls]
2025-01-28 Add first firmware version
    [PowerBoard-B_Cu.gbr, PowerBoard-B_Mask.gbr, PowerBoard-B_Silkscreen.gbr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]
2025-06-16 Add dV/dt for inrush current limitation on the main power line
    [PowerBoard.kicad_pcb, PowerBoard.kicad_sch]
2025-06-19 finish inrush current limiting
    [PowerBoard.kicad_pcb, PowerBoard.kicad_sch]
2025-06-20 finish v2.4.0
    [PowerBoard-B_Cu.gbr, PowerBoard-B_Mask.gbr, PowerBoard-B_Silkscreen.gbr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]
2025-06-20 rework the 5V switching
    [PowerBoard-B_Cu.gbr, PowerBoard-B_Mask.gbr, PowerBoard-B_Silkscreen.gbr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]
2025-06-24 adjust component values
    [PowerBoard.kicad_sch]
2026-03-15 Add files via upload
    - Použitie normovaných hodnôt súčiastok v dizajne
    Opravený typ diód a hodnota D9,D10,D11,D14.
    Opravená orientácia diód D9, D10, D11, D14.
    - Zmeny hodnôt komponentov
    Opravene hodnoty komponentov:
    5,5nF -> 5,6nF
    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
2026-03-15 Generate gerber production files
    [PowerBoard-B_Cu.gbr, PowerBoard-B_Mask.gbr, PowerBoard-B_Silkscreen.gbr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]
2026-08-14 Add a powerboard firmware version from Michael Klamár
2026-08-14 Make OCP switchable and set limits from the DC-DC ratings
    Over-current protection is now disabled by default and can be toggled at
    runtime with "OCP ON" / "OCP OFF" ("OCP" queries it). Some high-side drivers
    on this board were bridged after inrush current tripped them, so those
    branches cannot be opened in hardware - tripping them in software would only
    report TRIPPED while current kept flowing.
    Disabling protection does not disable monitoring. branchOverLimit[] is set
    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
2026-08-14 Add read-only RAW register dump command
    "RAW" prints, for every device: DEVICE_ID, CONFIG, ADC_CONFIG and SHUNT_CAL read
    back from the chip, the unconverted VBUS / VSHUNT / CURRENT / DIETEMP register
    words in hex and decimal, the conversion the firmware applies to each, and the
    shunt-derived current that the over-current check uses.
    The config read-back matters because writeWord() discards the result of
    Wire1.endTransmission(), so every write in initDevice() is unverified - a NACKed
    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
2026-08-15 Add JSON line protocol for machine consumption
    The board's output was a human table redrawn at 2 Hz: unframed, unsequenced,
    state encoded as English ("YES", "ACTIVE"), inconsistent column padding, and
    rows that can be switched off individually - so a parser could not even rely on
    which rows were present. This adds a line protocol intended for a ROS 2 node,
    with the table kept one command away.
    One JSON object per line, newline terminated. Four line types share the stream
    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
2026-08-15 Fix INA238 ADC_CONFIG: bus voltage and temperature were never converted
    initDevice() wrote ADC_CONFIG = 0xAB6A under a comment claiming "Continuous
    All". MODE is bits [15:12], and 0xA there is INA_MODE_CONTINUOUS_SHUNT --
    shunt only. The shunt kept converting, so current was always live, but BUS
    VOLTAGE and DIE TEMPERATURE held whatever the device converted before this
    register was written, i.e. the values at board boot.
    Measured on the rover over 237 telemetry frames: currents showed 23-104
    distinct values per rail, voltages and temperatures showed exactly one.
    This is also the "calibration offset" we chased earlier. The INA reported
    41.615 V while a meter fell 41.17 -> 40.80 -> 40.57; th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
    [INA238.cpp]
2026-08-15 Add the ROS 2 driver alongside the firmware it talks to
    The node lived only in a workspace on the rover's NUC, untracked by any
    repository - one re-image away from being lost.
    It belongs here rather than in its own repository because the two halves share
    a versioned wire protocol. Every field name and status bit is written twice,
    once in firmware/PowerBoard/Functions.cpp and once in the node. Kept apart,
    a schema change is two commits that can be merged, reviewed and deployed
    independently, and the failure mode is not a build error but silently
    misparsed telemetry. Together it is one commit and one diff, with
    jsonSchemaVersion and SUPPORTED_SCHEMA visible side by side.
    Adds a README docume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
    [powerboard_node.py, serial_line_reader.py]
2026-08-15 Poll the board at 10 Hz instead of 50 Hz
    The board emits one telemetry frame every 500 ms, so a 50 Hz poll loop spends
    most of its wakeups finding an empty buffer. That is affordable on the NUC and
    not on the rover's Raspberry Pi 4, where the SPI-attached CAN controller for
    the drive motors already saturates CPU0 on its own.
    Measured on that Pi, same synthetic 2 Hz stream through a pty:
    50 Hz 14.2% of a core
    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
